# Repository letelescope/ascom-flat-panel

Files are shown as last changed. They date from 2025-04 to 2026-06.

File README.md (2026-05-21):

# Le Telescope Flat Panel 







[![Build with PlatformIO](https://img.shields.io/badge/build%20with-PlatformIO-orange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)](https://platformio.org/)

 

Open source *ASCOM* and *INDI* driven automated flat panel for astrophotography. 

> ⚠ **DISCLAIMER**  
> This project is still very much work in progress. None of it is likely/expected to work at this stage !

---

## Introduction

This project is an open source initiative, under the MIT license, by *Le Telescope*. This is the v2 of a fully automated and drivable motorized flat panel/dust cap. The device is nicknamed FFFP. Don't ask why! If you still want to know, see the  [misc. section](#miscellaneous) of this readme.

This project should contain all you need to build your own *ASCOM* and/or *INDI* driven Flat Panel. 

- [firmware](./firmware/fffp_firmware/): Firware of the programble chip used to control the panel and its cover
- [drivers](./drivers/): Implementation of the drivers
  - [ASCOM](./drivers/ASCOM/) : Implementation of the *ASCOM* driver 
  - [INDI](./drivers/indi/) : Implementation of the *INDI* driver
- [electronics](./electronics/): Electronic schematics and PCB layouts
- [models](./models/): 3D models for the plat cap
- [specifications](./specifications/): Specifications of the project. Mainly the specs of the communication protocol between the drivers and the firmware.

This project, the protocol, the implementation of both the *ASCOM* driver and the firmware, the electronics and the 3D models are heavily inspired by the the work  of [Dark Sky Geek](https://github.com/jlecomte/). And more precisely: 
- [ascom-flat-panel](https://github.com/jlecomte/ascom-flat-panel)
- [ascom-wireless-flat-panel](https://github.com/jlecomte/ascom-wireless-flat-panel)
- [ascom-telescope-cover-v2](https://github.com/jlecomte/ascom-telescope-cover-v2)

Kudos to him. 

The Pulse Width Modulation (PWM), used to control the panel brightness, implementation is heavily inspired, or more accurately shamelessly ripped, from the work of [Khoih Hoang](https://github.com/khoih-prog) and more precisely [SAMD_PWM](https://github.com/khoih-prog/SAMD_PWM/). 

Kudos to him too.

Finally te INDI driver architecture follows very closely the official [Gemini Flat Panel](https://github.com/indilib/indi/blob/master/drivers/auxiliary/gemini_flatpanel.h) as well as teh [Flip Flat](https://github.com/indilib/indi/blob/master/drivers/auxiliary/flip_flat.h) implemtentations. 

----

## Construction

### Why a "motorized flat panel" ? And what do we mean by "motorized flat panel" ?

In this scenario a flat panel is made of two things
- A light panel with variable brightness
- A motorized cover

The cover is motorized using a servo motor and held in open/close positions using simple magnets. The lightpanel is made 
- either using LEDs and the variable brightness is achieved via pulse width modulation (PWM). 
- or eusing a EL panel and the variable brightness is achived usi a DAC (Digital to Analog Converter) coupled to an OA (Operation Amplifier) in non-inverting amplifier mode. 

This "electronico-mechanical" assembly is controlled via a SAMD21 based board with a custom firmware within a custom PCB. The SAMD21 is particullarly suited because:

- it can output 5V, that is needed to power the servo.
- it can output +3V3 and allow us to choose between 3V and 5V to power the LEDs.
- it has 16 bits timer counters necessary to achieve fast PWM. We do not want flickering flats...
- it has a real DAC output pin to alow "easy" dimming of a flat panel.

One can connect and send commands to the flat-panel using Serial (COM Port) over USB. When plugged in the device will be recognized by windows/linux as a COM device. 

Finally this is driven by ASCOM/INDI, such that one can fully automate taking flats following the acquisition sessions of our beloved night sky targets. 

> ⚠ **DISCLAIMER**  
> This project is built around the Seeeduino XIAO board that uses the ATSAMD21G18A-MU chip. This is the only board that we tested. This may work on other boards that uses these SAMD21 chips, but this may need some rework on the firware, the PCB layout and the mechanical assembly. 

Now that we have the big picture let's get real and build the thing !

[INSERT HERE SOME PHOTOS]

### Pre-requisites

Very few pre-requisites are necessary in order to build the flat panel. More precisely one will need to:

- have access to a 3D printer, to print the mechanical assembly parts
- have some soldering skills and a soldering kit, to solder the components to the custom PCB
- install PlateformIO, to upload the firmware
- love "diy-ing", because you may need to want/need to tweaks things a bit to make it work in your setup. 
  
And that's it ! For instance you won't need software developpement skills as both the driver and the firmware are usable as is. Moreover, the ASCOM driver installer is already pre-compiled and made available to the download. Unfortunaltely one cannot make an "installer" for the arduino firware. Yet using PlaterfomIO to upload the firmware is a matter of three clicks. 

> We chose PlatformIO instead of ArduinoIDE due to recent concerns about Arduino's Open Source commitment under Qualcomm, and ,icing on the cake, PlatformIO provides superior dependency and library management.

### Bill of material 

[TODO] ADD BILL OF MATERIAL 

### Get a coherent version. 

We heavily use the git version control "tags" to label released versions. We also leverage the "GitHub releases" that add the possibility to pin "binaries" (ie anything we want PCB layouts, Driver installers, mechanincal assembly 3D printer files,...) on "tagged" versions. 

When we deem a version is "usable" we tag it, ie we freeze this repository at a particular "commit", and create a release out of it. 

To access the various releases just got the [releases page](https://github.com/letelescope/ascom-flat-panel/releases/) of this repository.

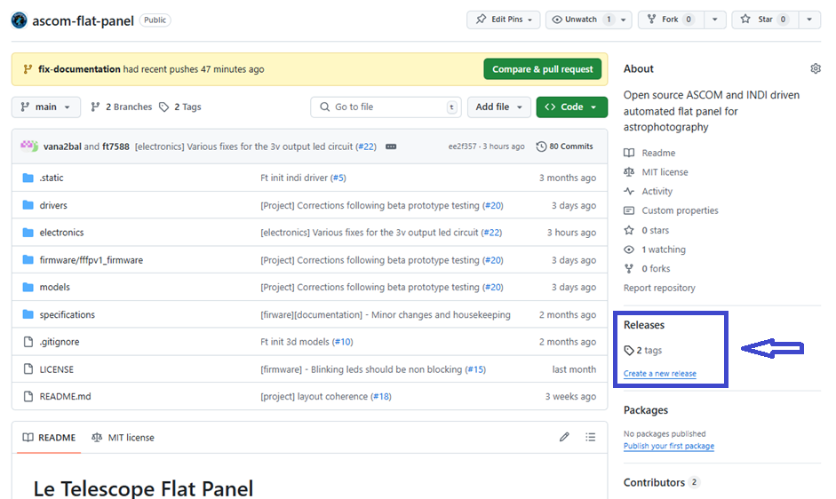
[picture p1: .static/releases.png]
Access the releases


And choose the release you want. The latest should be the "better". 

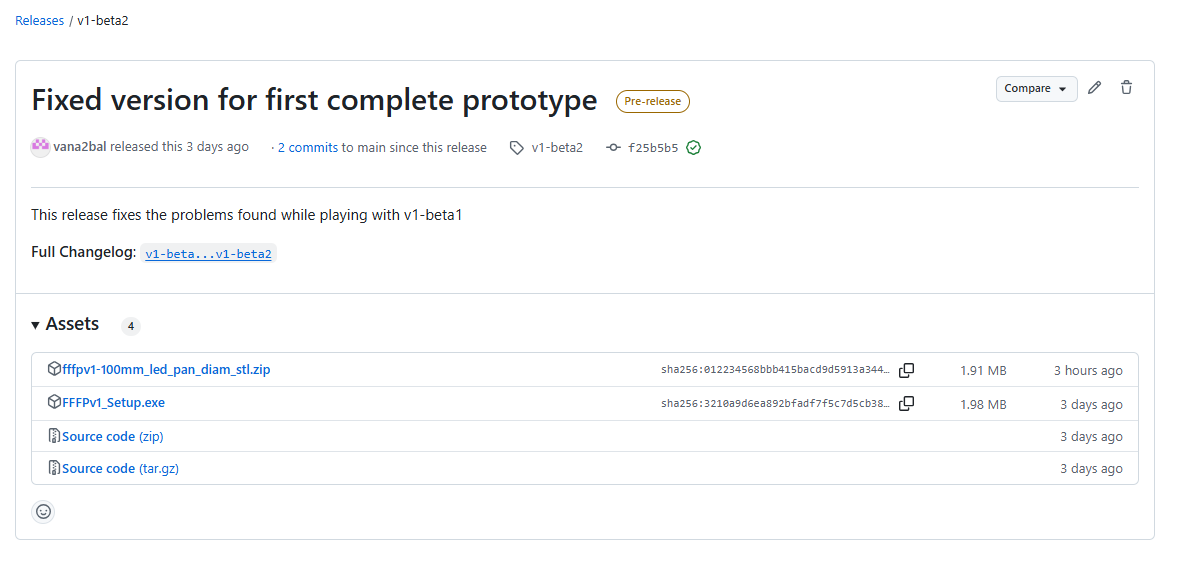
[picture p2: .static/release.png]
Access the content of a release


We recommend that you use one of these released version as they are coherent and tested. Be careful some release are labelled "pre-release" and should be used with caution. Those are developpement, beta and alpha version. Use it at you own risk like all the material on this repository. But even more in this case :D. 

In the same spirit, we do not recommend you use the "head" of the main branch (or any other branch) of this repository as this is work in progress and hence is not guaranteed to be stable or even usable...

> If you already have an FFFPV1, please note that both drivers and firmware **should** be backward compatible. You can use the latest version of both the ASCOM driver with your FFFPV1 without any issue and vice-versa: upload the new firmware on your FFFPV1 device and still use the legacy v1 driver. Yet we recommend you use the latest version of the driver, the firmware, the electronic circuit and the assembly as they all have been improved coherently.

### Electronic circuit

We provide three options for the electronic circuit. The difference is made on wether you want to use a led panel or a EL panel (You may not have the choice, as LED panels are restricted to smaller diameters). 

#### EL Panel option

This is certainely the "go to" solution, as this allows for a slicker and ligther mechanical assembly. Ans the electronics are not that much more difficut. 

- The The Pin "AO" (DAC) of the Seeeduino XIAO is used to control the LED brightness:
  - Is is directly connected to the non-invervint pin of ta TLC272 Op.Amp. The Ration of R1/R2 controls the amplifying contant (R = 1 + R1/R2) 
  - The output of the TLC272 is connected to the base of a  darlington transistor. Such that more current can flow to the EL Driver without worring too much about the life expectency of the TLC272
  -  The +12v needed for the Op Amp and the Driver is obtained using a DC/DC regulator

> ⚠ **WARNING**  
> The choice of Pin AO for DAC is not random. This is the only one on the Seeeduino XIAO (and SAM-D21 chips) capable to produce proper DAC. Please [see](https://ww1.microchip.com/downloads/en/DeviceDoc/SAM_D21_DA1_Family_DataSheet_DS40001882F.pdf). 

- The Pins "5,6,7"  of the Seeeduino XIAO are used for power control, position control and servo feedback:
  - Power control is connected, via a voltage divider bridge, to the gate of a IRLZ34N MOSFET.
  - Feedback is directly connected to the feedback pin of the servo.
  - Position control is directly connected to the position control pin of the servo.
  
- Servo VCC and Servo ground are decoupled using diodes.

- +12V and +5V are decoupled from ground using 10μF capacitors. It acts both as
  - an energy storage for a stable +5V/+12V output.
  - a "wire" for very high frequency spurious oscillations and effectively ground them. 

#### LED Panel schematics

This should be the go solution for most setups. Yet if you setup si particularly slow you may want to check the led versions. 

Here is the schematics for this option

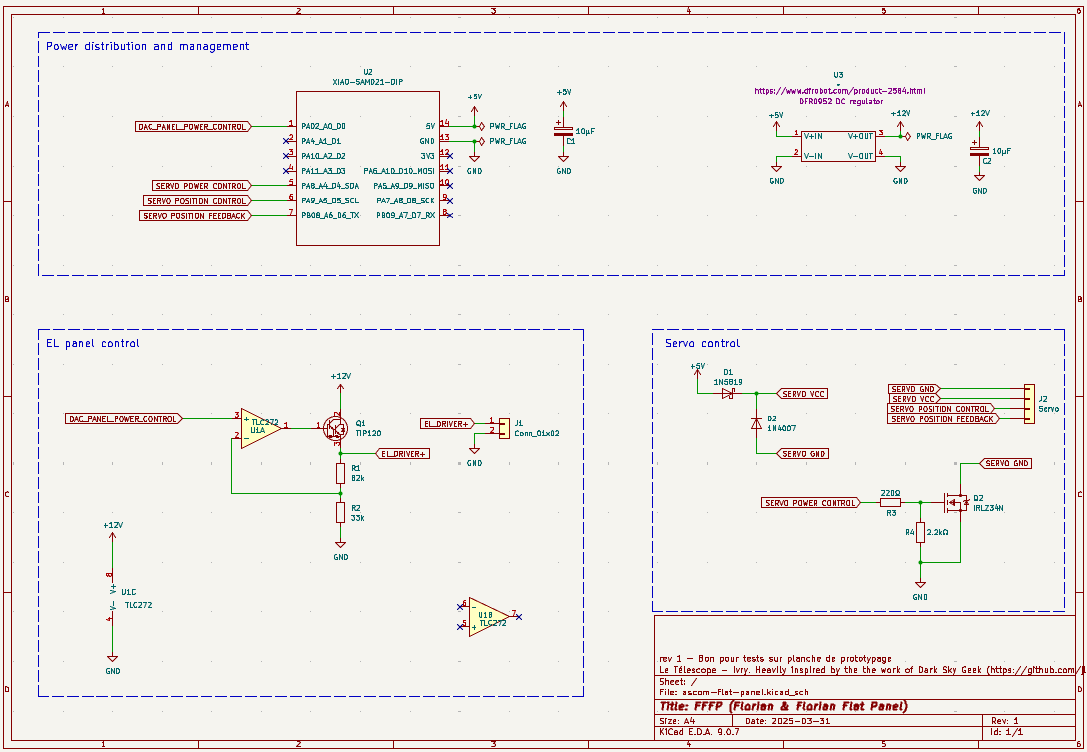
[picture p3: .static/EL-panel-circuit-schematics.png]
Circuit with EL panel


#### LED panel option

There are two options regarding the tension value used to power the LEDs: either +3V3 or +5V. But appart from that the two circuits share the same principles:

- The Pin "8"  of the Seeeduino XIAO is used to control the LED brightness:
  + It is connected, via a voltage divider bridge, to the gate of a IRLZ34N MOSFET.
  - The "+"terminal of the LEDs (strip or panel) is plugged to the constant +3V3 (or +5V) output of the Seeeduino
  - The "-" terminal of the LEDs (strip or panel) is connected to the drain of the IRLZ34N MOSFET. 
  - The source of the MOSFET is grounded. 
  - High frenquency PWM is used to swich rapidly ON and OFF the MOSFET, and allow to control the effective tension applied to the LEDs. 

> ⚠ **WARNING**  
> The choice of Pin 8 for PWM is not random. Not all pins of Seeeduino XIAO (and SAM-D21 chips) are capable to produce high frequency PWM. That's possible with Pin 8 because it use timer counter TCC1 which is 16bits.  And If you want to choose another pin please check the [documentation](https://ww1.microchip.com/downloads/en/DeviceDoc/SAM_D21_DA1_Family_DataSheet_DS40001882F.pdf) first. 

- The Pins "5,6,7"  of the Seeeduino XIAO are used for power control, position control and servo feedback:
  - Power control is connected, via a voltage divider bridge, to the gate of a IRLZ34N MOSFET.
  - Feedback is directly connected to the feedback pin of the servo.
  - Position control is directly connected to the position control pin of the servo.
  
- Servo VCC and Servo ground are decoupled using diodes.

- +5V (and +3V3 if needed) are decoupled from ground using 10μF capacitors. It acts both as
  - an energy storage for a stable +5V/+3V3 output.
  - a "wire" for very high frequency spurious oscillations and effectively ground them. 

##### The +3V3 output for LEDs

This is best suited for small refractors using fewer LEDs and/or fast optics. 

Here is the schematics for this option

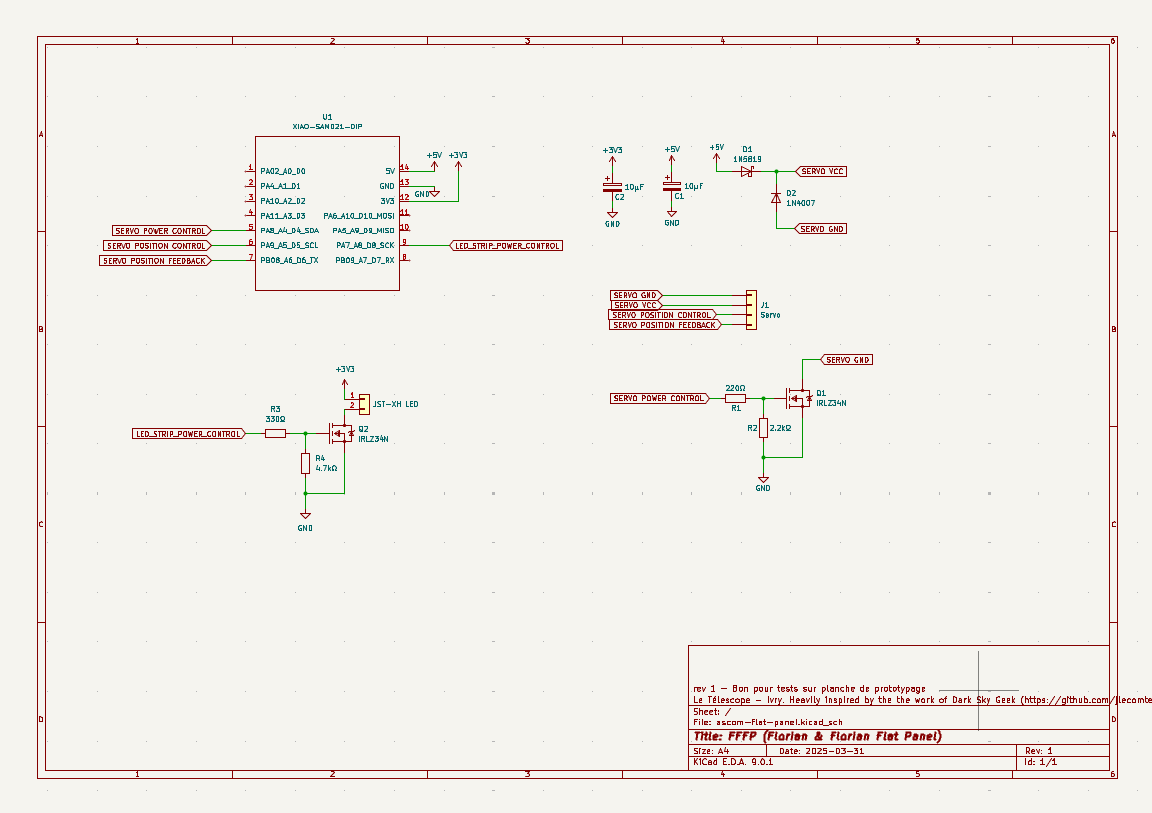
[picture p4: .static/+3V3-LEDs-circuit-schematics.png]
Circuit with +3V3 output for LEDs


##### The +5V output for LEDs

This is best suited for bigger tubes using a larger number of LEDs drawing more current. 

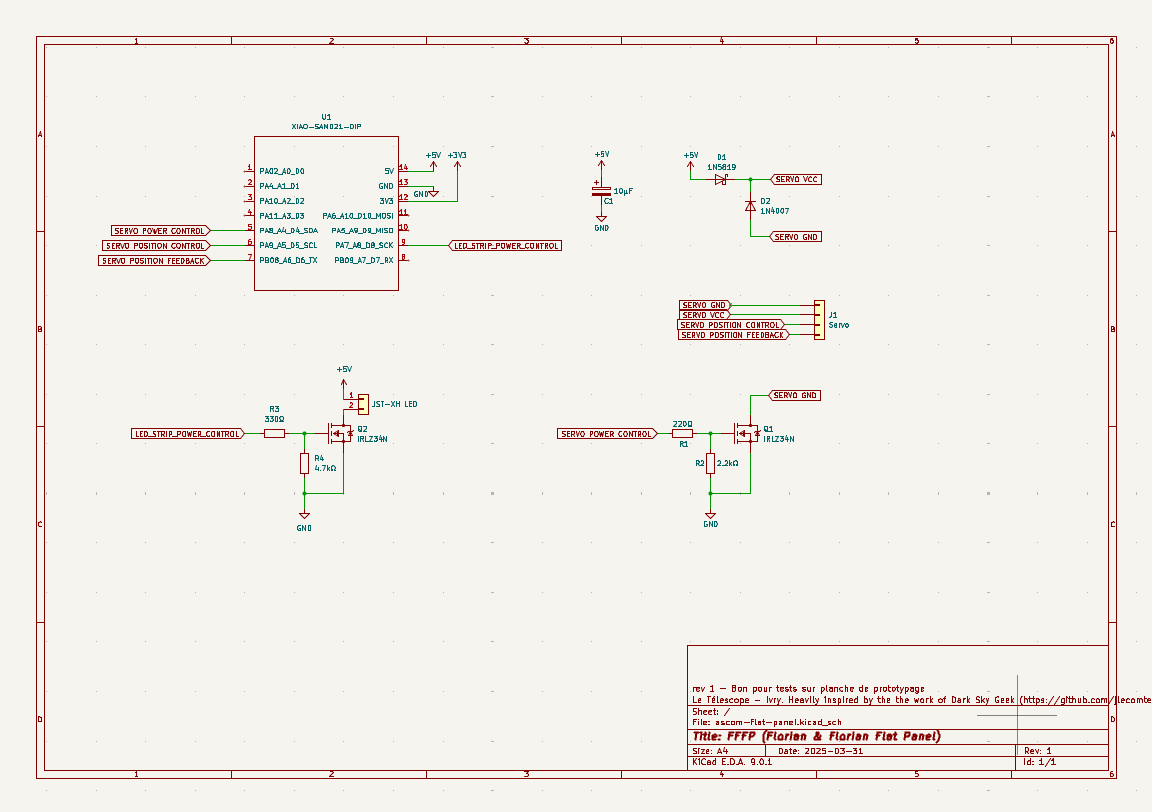
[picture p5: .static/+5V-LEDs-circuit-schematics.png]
Circuit with +5V output for LEDs


#### Cicruit layout breadbord validation

We recommend you prototype the circuit using breadbords first. 

- This can help you choose between the +5V and +3V3 version. A quick "hint", don't go for to bright ouputs for LEDs as a very bright panel is in fact not really needed when taking flats. Especially with fast optics. 
- This allows to check each component/part of the circuit independently. It's always better to find a faulty component before it is soldered on a PCB.
- It's always fun to prototype. 

Here is and example of what the "+5V" circuit may look like on a breadbord.

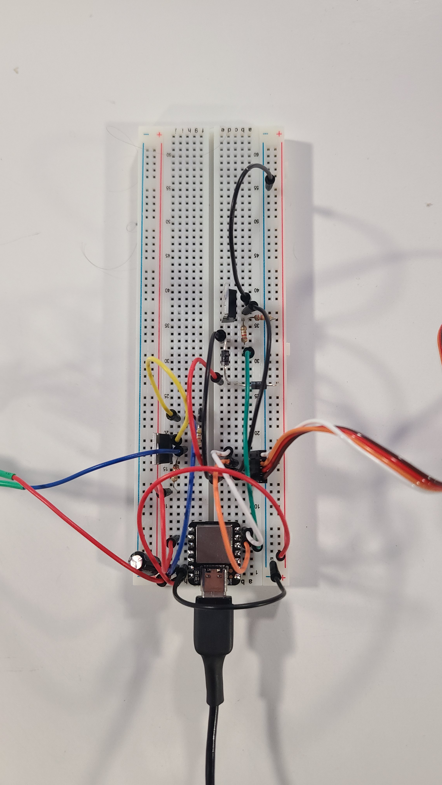
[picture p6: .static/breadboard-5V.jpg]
+5V circuit breadboard prototype
.

#### Printed Circuit Board

We had our PCBs printed by [PCBWay](https://www.pcbway.com/). If you do not modify the PCB layout and want to have it printed by PCBWay, you can just download one of the provided zip files that are pinned to the release (fffpv1-electronics-5V-LEDs-pcbway-files.zip or fffpv1-electronics-3V-LEDs-pcbway-files.zip, depending if you intend to use the +5V or +3V3 version).

If you want to modify the PCB layout, you have two options depending on the company you chose to print your PCB :
- If you chose PCBWay, just run a "Desing Rules Check" after your modifications are done to make sure there is no error (there may be warnings, but who cares about warnings ?). The PCBWay design rules are associated to the KiCAD project (they are implemented in the ascom-flat-panel.kicad_dru file). From here you can generate the fabrication files using the KiCAD interface and following the recommandations explained on the PCBWay website, OR you can simply install the PCBWay plugin for KiCAD, which will do the job for you in one click, and will drive you to the PCBWay website to complete your order (yes, we live in a fantastic era).
- If you chose another company, make sure their design rules are implemented to the KiCAD project. Depending on the company, you may find them in tables on the company's website and implement them using the KiCAD interface, or they can provide a .kicad_dru file you can use instead of the one we provide. Then perform a "Desing Rules Check" to check your modifications. Then you can generate the fabrication files using the KiCAD interface and following the recommandations provided by your supplier, or you can find out if there is a KiCAD plugin to do the job. Some suppliers will just take your KiCAD project and do all of this by their own, leaving you with basically nothing to do but creating an account and uploading your project (and pay, of course).

#### Firmware upload

#### Pre-requisite

The firmware needs to be uploaded using Visual Studio Code/PlateformIO . [PlateformIO setup section](#pre-requisites-1) of this documentation to set it. 

#### Upload the firware

1. Open the [firmware project](./firmware/fffp) from Visula Strudio Code/Plateform-IO. 

2. Connect the board via US. 
   
3. Select the board.
   
4. Click the "arrow" at the bottom to compile and upload the firmware on the board. 

The output should look something like: 

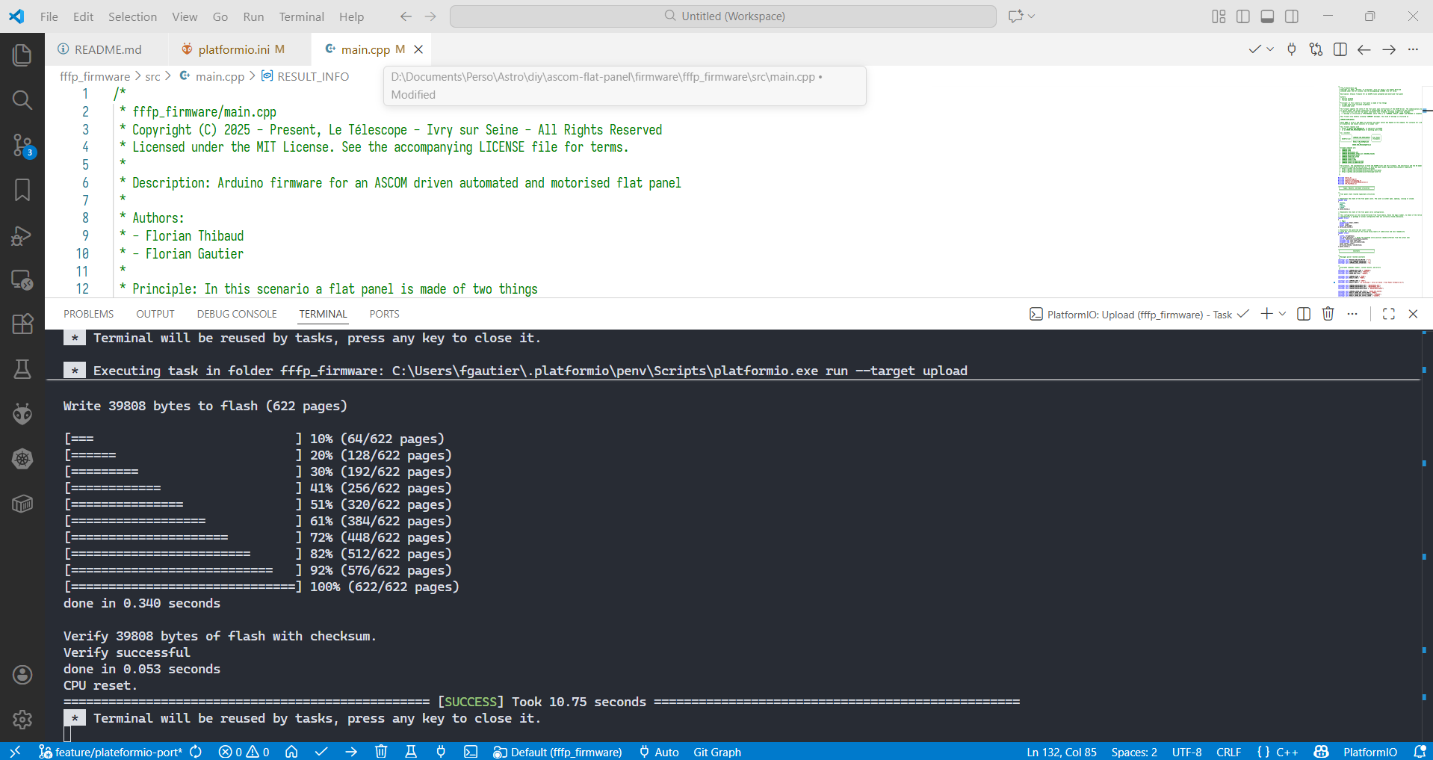
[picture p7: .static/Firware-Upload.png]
Arduino IDE firmware upload


#### Firmware checks

Once the firware is uploaded, do not disconnect the board yet. Still from the Arduino IDE open the "Serial Monitor". Once connected, in the console type:

``` console
COMMAND:PING
```
the board should answer

``` console
RESULT:PONG
```

Congrats! The Seeeduino is ready to act as your flat panel controller !

### Mechanical Assembly

Moving on to the actual print and build of the assembly. 

#### Prints from pre-designed assemblies

This repository (and therefore the tagged release version) contains a fully fonctional model. This is made to fit an Askar SQA-55 and uses premade 100mm led panel. It also feature an adapter to fit an Askar 71F. 

"Ready to print" STL files are also pinned to the release. Just download the fffpv1-100mm_led_pan_diam_stl.zip archive, unzip it. The archiver files are organized within two folders "Black" and "White". Files in he "black" repository can be printed in the color of your choice, but the one in the "white" folder should be printed using white PLA for better performance. This is especially true for the "spacer/diffuser" that, as its name suggests, helps homogenise the illumination of the panel.

#### Modification of pre-designed assemblies

#### Manufacturing sequence

#### Calibration of servo motor 

> ⚠ **WARNING**
> The firmware needs to be calibrated.

At first boot the LEDs will flash to indicate that it needs to be calibrated. 

> ⚠ **WARNING**
> Disconnect the servo from the mecanical assembly before launching the calibration procedure. 

Then from the IDE connect to the board and using the Arduino serial monitor send (type) the "command" 

``` console
COMMAND:COVER_CALIBRATION_RUN
``` 

The device should perform its calibration procedure and reply with 

``` console
RESULT:COVER_CALIBRATION_RUN@OK
```

Once it has completed, re-attach the right arm to the servo. The device is now ready to be used.

### ASCOM Driver Install

You can either used the installer to install the ASCOM driver or build it from source. For the sake of simplicity we recommend using the installer. 

#### Pre-compiled installer

The installer is pined on each release [releases page](https://github.com/letelescope/ascom-flat-panel/releases/). 

1. From the wanted release, download the file "FFFP_Setup.exe". 

2. "Double-click" on the downloaded file to launch it. 

   > ⚠ **WARNING**
   > Windows will warn that the publisher is unknown. This is perfectly fine. As buying a verified signing key, is definitely not a priority for us, we could not sign the installer. Yet this is perfectly safe to use it. 

3. Follow the instruction to install and register the driver. 

Congrats! You just installed the driver !

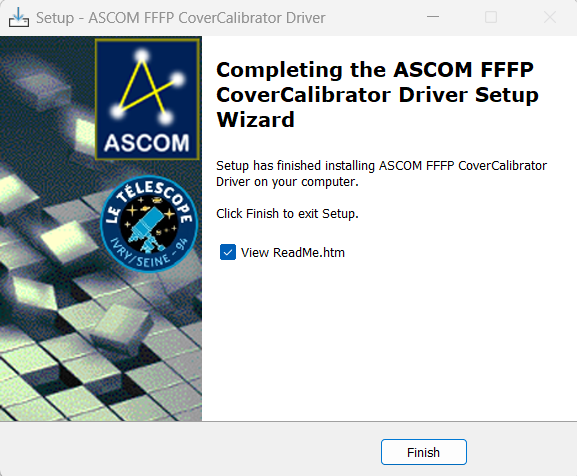
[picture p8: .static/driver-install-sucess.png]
driver install


#### Build from sources

To build it from source please check the relevant section of the "developpement documentation". 

#### Driver validation

Once install is complete, one can use the ASCOM profile explorer tool to check that this was installed properly. From the ASCOM profile explorer check that the *ASCOM CoverCalibrator Drvier for Le Telescope FFFP* is listed in the Cover Calibrators. 

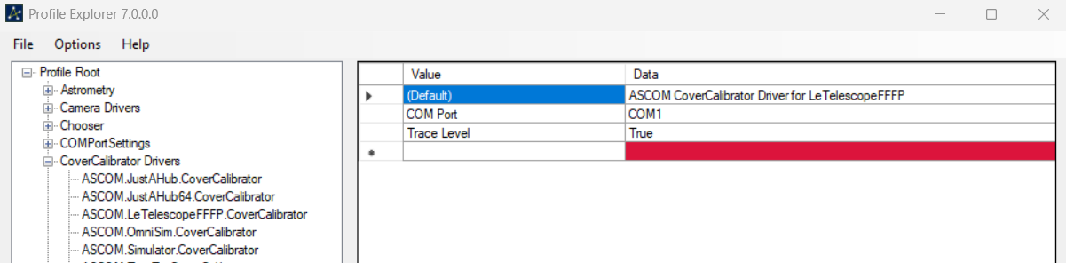
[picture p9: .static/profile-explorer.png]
ASCOM CoverCalibrator Drvier for Le Telescope FFFP
 

### INDI Driver

> ⚠ **WARNING**
> INDO driver is NOT functional DO NOT USE IT. 

---

## Testing

To avoid mass troubleshooting, one can test each component fairly separately. Below are listed some tests that can be used to validate the setup. Going from "unit test" to big-bang integration tests from your favourite acquisition software. 

### Firware "unit" testing

Once the firware is uploaded, one should already have tested that the seeduino was responsive. If not, reconnect the board via USB. From the Arduino IDE, open the "Serial Monitor". Once connected, in the console type:

``` console
COMMAND:PING
```
the board should answer

``` console
RESULT:PONG
```
If that's not the case, please make sure that you uploaded the (correct version of the) firmware firt. 

If that is indeed the case, congrats you are ready to test more "interesting" features of the firmware.

#### Set brightness levels

From the "Serial Monitor", in the console type the following command to adjust the LED panel brightness level:

``` console
COMMAND:BRIGHTNESS_SET@1024
```
the board should answer in the console

``` console
RESULT:BRIGHTNESS_SET@1024
```
In parallel, if it is connected to the board, the light panel should have been turned on. Feel free to change the value (number after the '@') to adjust the brightness. Max allowed value is 2047 and min value is 0. 

Use ```COMMAND:BRIGHTNESS_RESET``` to switch off the panel.

Congrats the variable light panel is functionnal. 

#### Open/Close the cover

> ⚠ **WARNING**
> To be able to open/close the panel, the panel should be calibrated first. Check the "mechanical assembly" section for the procedure. 

When turned on, the panel should be closed. To open it, from the "Serial Monitor", in the console type the following command:

``` console
COMMAND:COVER_OPEN
```
the panel should start moving and the board should answer in the console

``` console
RESULT:COVER_OPEN@OK
```

Once open to close it simply type in the consle

``` console
COMMAND:COVER_CLOSE
```
the panel should start moving and the board should answer in the console

``` console
RESULT:COVER_CLOSE@OK
```

Finally at any given time, to know the status of the mecanical panel type 

``` console
COMMAND:COVER_GET_STATE
```
the panel should start moving and the board should answer in the console

``` console
RESULT:COVER_GET@{panel.cover}
```

where panel.cover is string human readable translation of the current cover state. Possible values are in [**OPEN**, **OPENING**, **CLOSING**,]; 

Congrats the motorized cover is functionnal. 

### Driver "unit testing"

After install completion, one should already have used the ASCOM profile explorer tool to check that this was installed properly. If that's not the case from the ASCOM profile explorer check that the *ASCOM CoverCalibrator Drvier for Le Telescope FFFP* is listed in the Cover Calibrators. 

ASCOM CoverCalibrator Drvier for Le Telescope FFFP 

1. Then check that the driver is instiable using the ASCOM diagnostic tools
   
   a. Select the "Cover Calibrator" device type and elect the "FFPV1 Cover Calibrator"

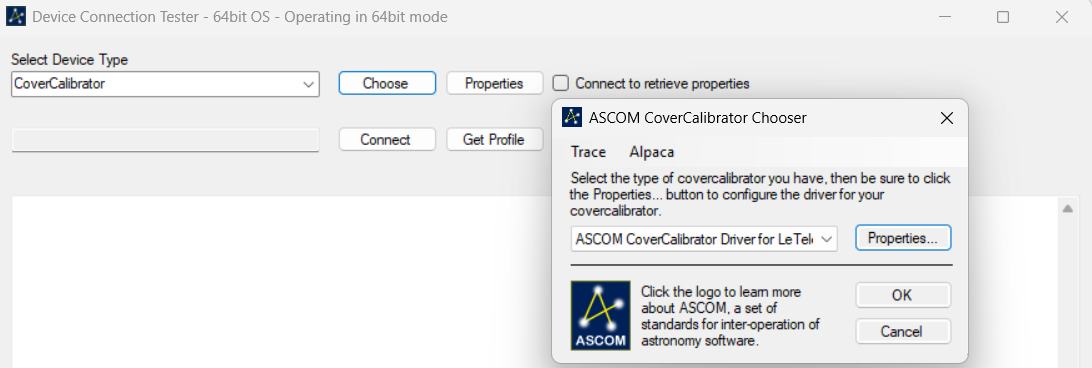
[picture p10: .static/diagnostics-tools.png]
Cover Calibrator device type


   b. Find and configure the "properties" of the driver

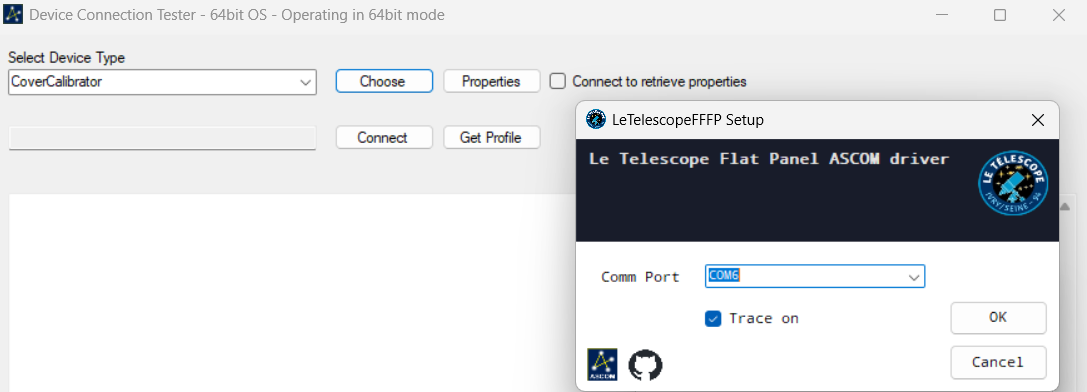
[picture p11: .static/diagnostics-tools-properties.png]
Driver properties


   b. Connect to the driver. Expect nothing much to happen. 

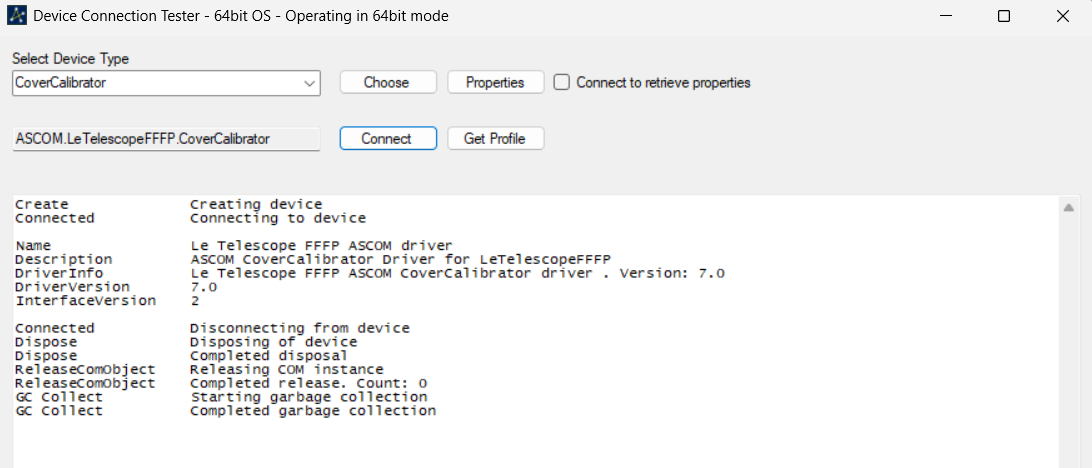
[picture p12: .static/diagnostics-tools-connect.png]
Connect driver


Congrats the driver seems to work as expected !

### Connect to the panel from N.I.N.A via ASCOM

Great ! If you read this, at this stage, the firware, the driver and the mecanical assembly should work, or at least one should be confident enough that they are working. Let's make the final test (and the only one relevant in fact). Let's take some flats from N.I.N.A. 

## Usage

The FFFP should be now be fully usable and drivable from N.I.N.A. 

### Flat-Panel Connection

Let's connect to the flat panel. 

0. Plug the flat panel to the computer via USB

In the equipment tab, from the flat panel section:

1. Select the *ASCOM CoverCalibrator Drvier for Le Telescope FFFP*.
2. Click the gear icon and select the correct COM Port. 
3. Hit OK to save the configuration.
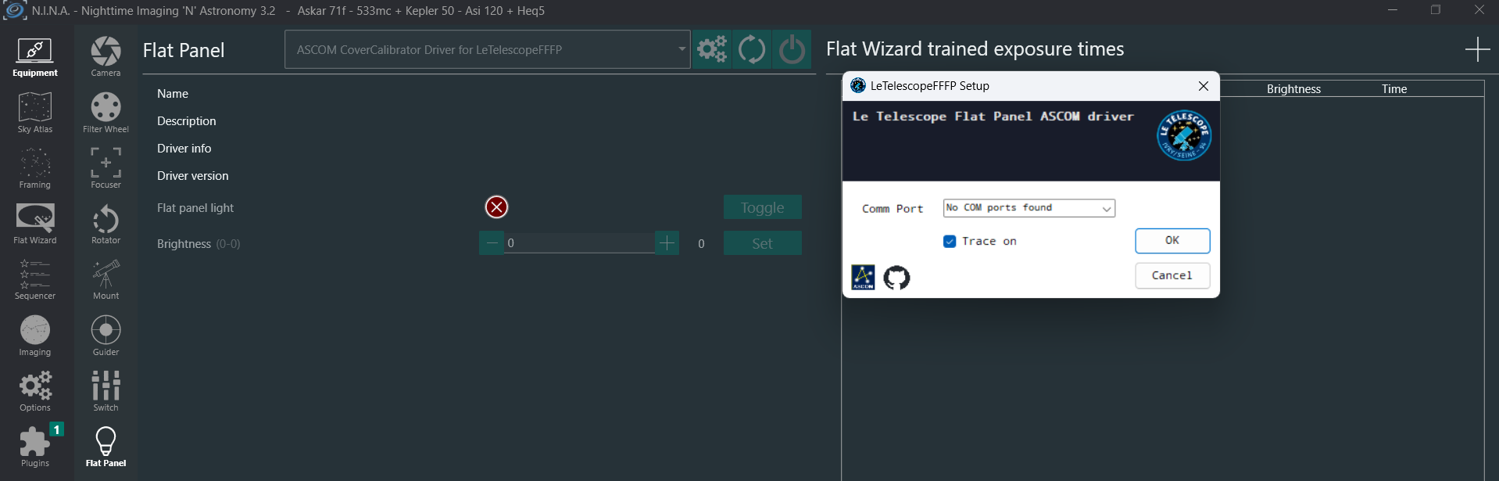
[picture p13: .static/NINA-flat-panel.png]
N.I.N.A Flat Panel equipement section
   

4. Click the "power" button to connect to the flat panel. 
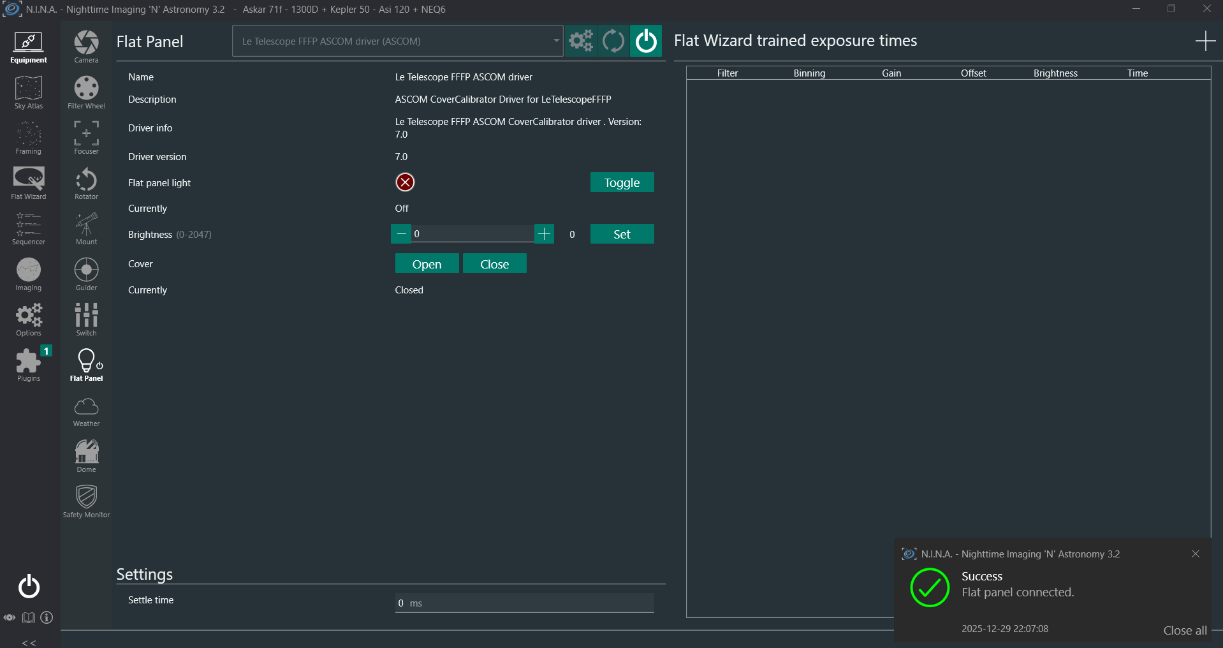
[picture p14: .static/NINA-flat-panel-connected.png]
N.I.N.A Flat Panel connection
   

From there you can turn on and off the panel, set the wanted brightness and/or open/close the cover. 

### N.I.N.A smart flats

Let's now use the N.I.N.A smart flats capabilities to automate flat frames recording.

#### Auto-exposure

#### Auto-brightness

---

## Developpement 

### Principle

In this scenario a flat panel is made of two things
- A light panel with variable brightness
- A motorized cover

The firmware updates the state of the flat panel upon instructions of the (*ASCOM* or *INDI*) driver. The communication protocol is serial based. The serial connection is established via USB. Here is a a summary of the protocol 
- Both the driver and the flat panel (its firmware) exchange single line messages; ie terminated by '\n'.
- A message is structured as TYPE:MESSAGE, where TYPE is in "COMMAND, RESULT, ERROR" and MESSAGE is alaphanumerical with spaces and "@"

The driver emmits and the firmware handles the incoming "COMMAND" messages. This kind of message is stuctured as 

- `COMMAND:NAME[@ARGS]` where NAME is [A-Z_]+ and ARGS may be optional or mandatory and their nature may depend on the command.

The firmware then responds with 
- either a `RESULT:CMD_NAME@VALUE` if operation succeeded
- or an `ERROR:ERR_MESSAGE@DETAILS` if anything went wrong

In a nutshell

     -----------------                           ------------
    |                 |                         |            |
    |      Driver     | COMMAND:CMD_NAME[@ARGS] | Flat Panel |
    | (ASCOM or INDI) | --------------------->  | (firmware) |
    |                 | <---------------------  |            |
     -----------------  RESULT:CMD_NAME@VALUE    ------------
                                or
                        ERROR:ERR_MESSAGE@DETAILS

More details on this protocol are provided in [protocol.md](./specifications/protocol.md)

### Softwares developpement and compilations

#### Seeduino firmware

The firware is entirely buildable and uploadable using the Arduino IDE
 
##### Pre-requisites 

- [Download](https://code.visualstudio.com/download) and install the Visual Studio Code or the IDE of your choice
- [Download](https://platformio.org/install/ide) PlatformIO IDE and/or install the PlatformIO extension for Visual Studio Code
- No need to download and configure the Seeduino XIAO board for PlateformIO as this is already done in the [platformio.ini](./firmware/fffp_firmware/platformio.ini) file of the firmware project.
- No need to download and install the official Adafruit SleepyDog library  as this is already done in the [platformio.ini](./firmware/fffp_firmware/platformio.ini). This is used to properly handle disconnection. 

##### Compile and upload the firmware

1) Using PlateformIO IDE, open the [project](./firmware/fffp_firmware/)

2) Click "PlateformIO: Build" to compile the firmware. The output should be something like 
   ``` console
   Processing seeed_xiao (platform: atmelsam; board: seeed_xiao; framework: arduino)
   --------------------------------------------------------------------------------------------------------------------------------------------------
   Verbose mode can be enabled via `-v, --verbose` option
   CONFIGURATION: https://docs.platformio.org/page/boards/atmelsam/seeed_xiao.html
   PLATFORM: Atmel SAM (8.3.0) > Seeeduino XIAO
   HARDWARE: SAMD21G18A 48MHz, 32KB RAM, 256KB Flash
   DEBUG: Current (atmel-ice) External (atmel-ice, blackmagic, jlink)
   PACKAGES:
    - framework-arduino-samd-seeed @ 1.8.5
    - framework-cmsis @ 2.50400.181126 (5.4.0)
    - framework-cmsis-atmel @ 1.2.2
    - toolchain-gccarmnoneeabi @ 1.70201.0 (7.2.1)
   LDF: Library Dependency Finder -> https://bit.ly/configure-pio-ldf
   LDF Modes: Finder ~ chain, Compatibility ~ soft
   Found 20 compatible libraries
   Scanning dependencies...
   Dependency Graph
   |-- Servo @ 1.3.0
   |-- Adafruit SleepyDog Library @ 1.6.5
   |-- FF_Flat_Panel
   |-- FlashStorage @ 0.5.0
   |-- SAMD21_PWM
   Building in release mode
   Compiling .pio\build\seeed_xiao\src\main.cpp.o
   Compiling .pio\build\seeed_xiao\libae5\Servo\avr\Servo.cpp.o
   Compiling .pio\build\seeed_xiao\libae5\Servo\esp32\Servo.cpp.o
   Compiling .pio\build\seeed_xiao\libae5\Servo\mbed\Servo.cpp.o
   Compiling .pio\build\seeed_xiao\libae5\Servo\megaavr\Servo.cpp.o
   Compiling .pio\build\seeed_xiao\libae5\Servo\nrf52\Servo.cpp.o
   Compiling .pio\build\seeed_xiao\libae5\Servo\renesas\Servo.cpp.o
   Compiling .pio\build\seeed_xiao\libae5\Servo\sam\Servo.cpp.o
   Compiling .pio\build\seeed_xiao\libae5\Servo\samd\Servo.cpp.o
   Compiling .pio\build\seeed_xiao\libae5\Servo\stm32f4\Servo.cpp.o
   Compiling .pio\build\seeed_xiao\libae5\Servo\xmc\Servo.cpp.o
   Compiling .pio\build\seeed_xiao\libae5\Servo\zephyr\Servo.cpp.o
   Compiling .pio\build\seeed_xiao\lib2bf\Adafruit SleepyDog Library\Adafruit_SleepyDog.cpp.o
   Compiling .pio\build\seeed_xiao\lib2bf\Adafruit SleepyDog Library\utility\WatchdogAVR.cpp.o
   Compiling .pio\build\seeed_xiao\lib2bf\Adafruit SleepyDog Library\utility\WatchdogESP32.cpp.o
   Compiling .pio\build\seeed_xiao\lib2bf\Adafruit SleepyDog Library\utility\WatchdogESP8266.cpp.o
   Compiling .pio\build\seeed_xiao\lib2bf\Adafruit SleepyDog Library\utility\WatchdogKinetisK.cpp.o
   Compiling .pio\build\seeed_xiao\lib2bf\Adafruit SleepyDog Library\utility\WatchdogKinetisL.cpp.o
   Compiling .pio\build\seeed_xiao\lib2bf\Adafruit SleepyDog Library\utility\WatchdogNRF.cpp.o
   Compiling .pio\build\seeed_xiao\lib2bf\Adafruit SleepyDog Library\utility\WatchdogRP2040.cpp.o
   Compiling .pio\build\seeed_xiao\lib2bf\Adafruit SleepyDog Library\utility\WatchdogSAMD.cpp.o
   Compiling .pio\build\seeed_xiao\libc78\FlashStorage\FlashStorage.cpp.o
   Archiving .pio\build\seeed_xiao\libae5\libServo.a
   Compiling .pio\build\seeed_xiao\FrameworkArduinoVariant\variant.cpp.o
   Compiling .pio\build\seeed_xiao\FrameworkArduino\IPAddress.cpp.o
   Compiling .pio\build\seeed_xiao\FrameworkArduino\IPv6Address.cpp.o
   Archiving .pio\build\seeed_xiao\lib2bf\libAdafruit SleepyDog Library.a
   Compiling .pio\build\seeed_xiao\FrameworkArduino\Print.cpp.o
   Compiling .pio\build\seeed_xiao\FrameworkArduino\Reset.cpp.o
   Compiling .pio\build\seeed_xiao\FrameworkArduino\Retarget.cpp.o
   Compiling .pio\build\seeed_xiao\FrameworkArduino\SERCOM.cpp.o
   Archiving .pio\build\seeed_xiao\libc78\libFlashStorage.a
   Archiving .pio\build\seeed_xiao\libFrameworkArduinoVariant.a
   Compiling .pio\build\seeed_xiao\FrameworkArduino\Stream.cpp.o
   Compiling .pio\build\seeed_xiao\FrameworkArduino\StreamString.cpp.o
   Compiling .pio\build\seeed_xiao\FrameworkArduino\Tone.cpp.o
   Compiling .pio\build\seeed_xiao\FrameworkArduino\USB\CDC.cpp.o
   Compiling .pio\build\seeed_xiao\FrameworkArduino\USB\PluggableUSB.cpp.o
   Compiling .pio\build\seeed_xiao\FrameworkArduino\USB\SAMD21_USBDevice.cpp.o
   Compiling .pio\build\seeed_xiao\FrameworkArduino\USB\USBCore.cpp.o
   Compiling .pio\build\seeed_xiao\FrameworkArduino\USB\samd21_host.c.o
   Compiling .pio\build\seeed_xiao\FrameworkArduino\Uart.cpp.o
   Compiling .pio\build\seeed_xiao\FrameworkArduino\WInterrupts.c.o
   Compiling .pio\build\seeed_xiao\FrameworkArduino\WMath.cpp.o
   Compiling .pio\build\seeed_xiao\FrameworkArduino\WString.cpp.o
   Compiling .pio\build\seeed_xiao\FrameworkArduino\abi.cpp.o
   Compiling .pio\build\seeed_xiao\FrameworkArduino\avr\dtostrf.c.o
   Compiling .pio\build\seeed_xiao\FrameworkArduino\base64.cpp.o
   Compiling .pio\build\seeed_xiao\FrameworkArduino\cbuf.cpp.o
   Compiling .pio\build\seeed_xiao\FrameworkArduino\cortex_handlers.c.o
   Compiling .pio\build\seeed_xiao\FrameworkArduino\delay.c.o
   Compiling .pio\build\seeed_xiao\FrameworkArduino\hooks.c.o
   Compiling .pio\build\seeed_xiao\FrameworkArduino\itoa.c.o
   Compiling .pio\build\seeed_xiao\FrameworkArduino\libb64\cdecode.c.o
   Compiling .pio\build\seeed_xiao\FrameworkArduino\libb64\cencode.c.o
   Compiling .pio\build\seeed_xiao\FrameworkArduino\main.cpp.o
   Compiling .pio\build\seeed_xiao\FrameworkArduino\math_helper.c.o
   Compiling .pio\build\seeed_xiao\FrameworkArduino\new.cpp.o
   Compiling .pio\build\seeed_xiao\FrameworkArduino\pulse.c.o
   Compiling .pio\build\seeed_xiao\FrameworkArduino\pulse_asm.S.o
   Compiling .pio\build\seeed_xiao\FrameworkArduino\startup.c.o
   Compiling .pio\build\seeed_xiao\FrameworkArduino\wiring.c.o
   Compiling .pio\build\seeed_xiao\FrameworkArduino\wiring_analog.c.o
   Compiling .pio\build\seeed_xiao\FrameworkArduino\wiring_digital.c.o
   Compiling .pio\build\seeed_xiao\FrameworkArduino\wiring_private.c.o
   Compiling .pio\build\seeed_xiao\FrameworkArduino\wiring_pwm.cpp.o
   Compiling .pio\build\seeed_xiao\FrameworkArduino\wiring_shift.c.o
   C:\Users\fgautier\.platformio\packages\framework-arduino-samd-seeed\cores\arduino\wiring_analog.c:35:12: warning: '_dacResolution' defined but not used [-Wunused-variable]
    static int _dacResolution = 10;
               ^~~~~~~~~~~~~~
   C:\Users\fgautier\.platformio\packages\framework-arduino-samd-seeed\cores\arduino\wiring_pwm.cpp: In function 'void noPwm(uint32_t)':
   C:\Users\fgautier\.platformio\packages\framework-arduino-samd-seeed\cores\arduino\wiring_pwm.cpp:374:13: warning: unused variable 'tcChannel' [-Wunused-variable]
        uint8_t tcChannel = GetTCChannelNumber(pinDesc.ulPWMChannel);
                ^~~~~~~~~
   Archiving .pio\build\seeed_xiao\libFrameworkArduino.a
   Linking .pio\build\seeed_xiao\firmware.elf
   c:/users/fgautier/.platformio/packages/toolchain-gccarmnoneeabi/bin/../lib/gcc/arm-none-eabi/7.2.1/../../../../arm-none-eabi/bin/ld.exe: warning: changing start of section .bss by 4 bytes
   c:/users/fgautier/.platformio/packages/toolchain-gccarmnoneeabi/bin/../lib/gcc/arm-none-eabi/7.2.1/../../../../arm-none-eabi/bin/ld.exe: warning: changing start of section .bss by 4 bytes
   c:/users/fgautier/.platformio/packages/toolchain-gccarmnoneeabi/bin/../lib/gcc/arm-none-eabi/7.2.1/../../../../arm-none-eabi/bin/ld.exe: warning: changing start of section .bss by 4 bytes
   c:/users/fgautier/.platformio/packages/toolchain-gccarmnoneeabi/bin/../lib/gcc/arm-none-eabi/7.2.1/../../../../arm-none-eabi/bin/ld.exe: warning: changing start of section .bss by 4 bytes
   c:/users/fgautier/.platformio/packages/toolchain-gccarmnoneeabi/bin/../lib/gcc/arm-none-eabi/7.2.1/../../../../arm-none-eabi/bin/ld.exe: warning: changing start of section .bss by 4 bytes
   Checking size .pio\build\seeed_xiao\firmware.elf
   Advanced Memory Usage is available via "PlatformIO Home > Project Inspect"
   RAM:   [=         ]   9.4% (used 3064 bytes from 32768 bytes)
   Flash: [==        ]  15.2% (used 39768 bytes from 262144 bytes)
   Building .pio\build\seeed_xiao\firmware.bin
   ========================================================== [SUCCESS] Took 7.97 seconds ==========================================================
   ```

   Don't worry to much about the warnings. Those are only warnings and can be safely igonered c.f. [arduino forum](https://forum.arduino.cc/t/web-ide-error-changing-start-of-section-by-4-bytes/1218049) and [adafruit forum](https://forums.adafruit.com/viewtopic.php?t=189483#p917530) .

1) Connect the Seeeduino and  "PlateformIO: Build"to test it

##### Warning - Firmware calibrarion

The firmware needs to be calibrated. At first boot the leds will flash to indicate that it needs to be calibrated. 

> **WARNING**
> Disconnect the servo from the mecanical assembly before launching the calibration procedure. 

Then from the IDE connect to the board and using the Arduino serial monitor send (type) the "command" 

``` console
COMMAND:COVER_CALIBRATION_RUN
``` 

The device should perform its calibration procedure and reply with 

``` console
RESULT:COVER_CALIBRATION_RUN@OK
```

Once it has completed, re-attach the right arm to the servo. The device is now ready to be used.

#### ASCOM Driver

The ASCOM driver is a C# .Net project that have been first created using the ASCOM 6 Visual Studio 2022 templates. Hence we recommend using Visual Studio 2022 when building it. Feel free to change this procedure to match your tooling. 

##### Pre-requisites 
 
- [ASCOM 7](https://github.com/ASCOMInitiative/ASCOMPlatform/releases/tag/v7.1.1) plateform
- [Visual Studio 2022](https://visualstudio.microsoft.com/fr/vs/). Comunity edition is totally fine. 
- A fully functional [ASCOM developper environement](https://ascom-standards.org/COMDeveloper/Index.htm) . Especiall, you may want to add the ASCOM "extensions" to Visual Studio.

##### Compile and register the driver

1) Open the ["solution"](./drivers/ASCOM/ASCOM_7_Driver/ASCOM_7_Driver.sln) from Visual Studio 2022

2) Compile the project using "Ctrl + Shift + B". The result in the console should look something like
  
   ``` console
   Génération démarrée à 14:12...
   1>------ Début de la génération : Projet : ASCOM_7_Driver, Configuration : Debug Any CPU ------
   1>  ASCOM_6_Driver -> D:\Documents\Perso\Astro\diy\ascom-flat-panel\ASCOM_drivers\ASCOM_7_Driver\bin\Debug\ASCOM.LeTelescopeFFFPV1.exe
   ========== Build : 1 réussite(s), 0 échec(s), 0 à jour, 0 ignorée(s) ==========
   ========== Build s’est terminée à 14:12 et a duré 10,405 secondes ==========
   ```

3) The first time you compile the server you must "register it" on the ASCOM plateform. Open an "elevated" command prompt (with admin priviledges) at the folder where the local server executable is located. Run the local server exe with the /regserver parameter which will create the entry that appears in the ASCOM Chooser. 
  
   ``` console
   .\ASCOM.LeTelescopeFFFP.exe /regserver
   ```

   **This registration only needs to be done once*.

4) You can now launch the driver from any ASCOM client, e.g. N.I.N.A or the ASCOM Diagnostic tool

##### Warning - When used with N.I.N.A

As of N.I.N.A 3.1.HF2, the "ASCOM device instance reference " is not disposed when connection failed. In our setup this may happen if the flat panel is not connected to the PC. In this scenario, the connection will fail, but a "driver process" will hang, waiting for N.I.N.A to dispose of the reference.

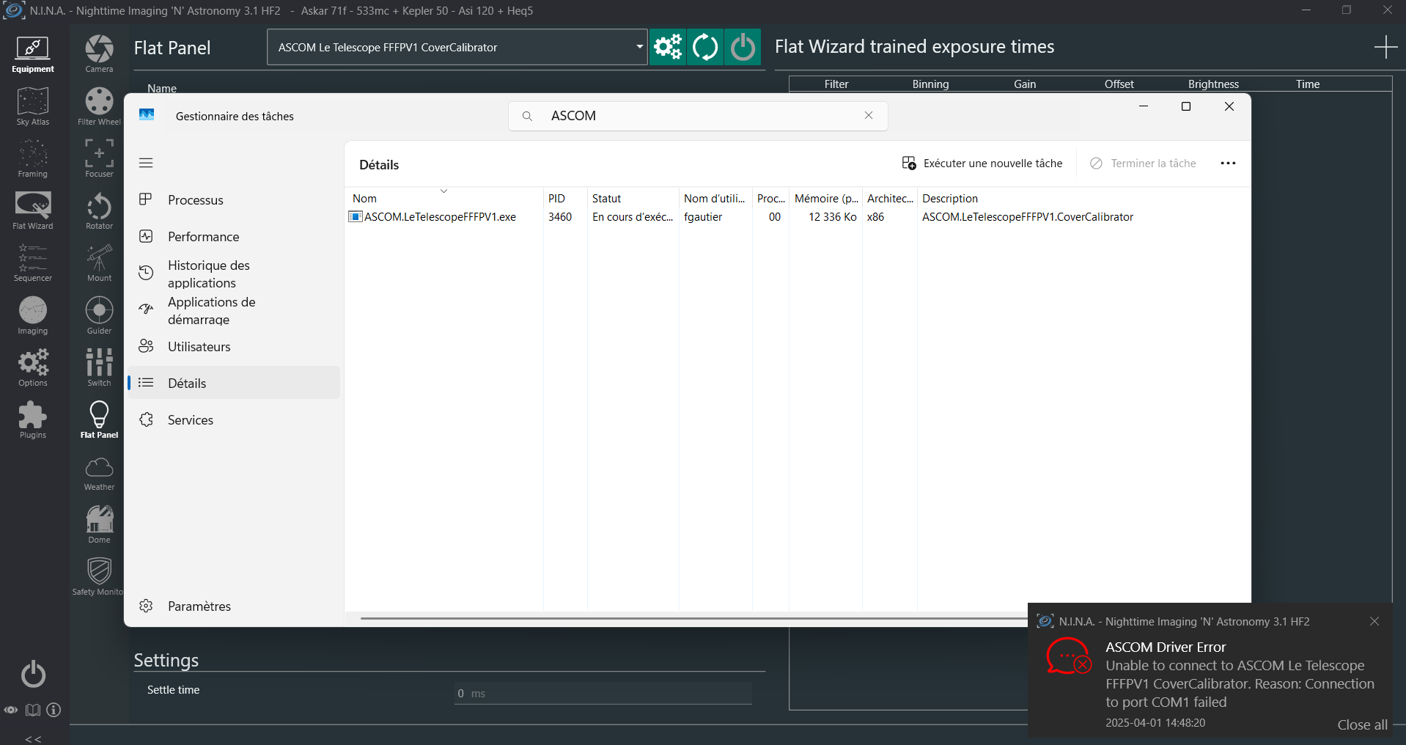
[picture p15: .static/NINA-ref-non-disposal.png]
NINA doeas not dispose of ASCOM reference


This is a known bug c.f. [nina-issue-1378](https://bitbucket.org/Isbeorn/nina/issues/1378/device-instance-not-disposed-when) and [ascom developers  group thread](https://ascomtalk.groups.io/g/Developer/topic/112002512). 

If this happens and some weird side effect happen on reconnection. Just disconnect from the device. Kill the dangling process in the task manager. And reconnect. 

### Indi driver

The indi driver is in its **really** early developement phase. It should no be used for anything else but developement. 

#### Pre-requisite

- A fully functional [Indi driver developer environement](https://docs.indilib.org/drivers/basics/project-setup.html). On Windows we recommend using a WSL2 environment. 
- One can also look at how to dev on "indi", c.f. the [getting started](https://docs.indilib.org/getting-started/)

#### Compile and install the driver

in the [indi](./drivers/indi/indi_driver/) directory, from VSCode integrated terminal or anyother terminal run

``` console
mkdir -p build
cd build
cmake -DCMAKE_INSTALL_PREFIX=/usr -DCMAKE_BUILD_TYPE=Debug ../
make
sudo make install
```

or 

``` console
./make-install.sh
```

The output should be something along the lines of:

``` console
-- The C compiler identification is GNU 13.3.0
-- The CXX compiler identification is GNU 13.3.0
-- Detecting C compiler ABI info
-- Detecting C compiler ABI info - done
-- Check for working C compiler: /usr/bin/cc - skipped
-- Detecting C compile features
-- Detecting C compile features - done
-- Detecting CXX compiler ABI info
-- Detecting CXX compiler ABI info - done
-- Check for working CXX compiler: /usr/bin/c++ - skipped
-- Detecting CXX compile features
-- Detecting CXX compile features - done
-- Found INDI: /usr/lib/x86_64-linux-gnu/libindidriver.so;/usr/lib/x86_64-linux-gnu/libindiAlignmentDriver.so (found version "2.1.9")
-- Found NOVA: /usr/lib/x86_64-linux-gnu/libnova.so
-- Found ZLIB: /usr/lib/x86_64-linux-gnu/libz.so (found version "1.3")
-- Found GSL: /usr/include (found version "2.7.1")
-- Performing Test COMPATIBLE_FORTIFY_SOURCE
-- Performing Test COMPATIBLE_FORTIFY_SOURCE - Success
-- Configuring done (2.3s)
-- Generating done (0.0s)
-- Build files have been written to: /home/florian/documents/diy/ascom-flat-panel/drivers/indi/indi_driver/build
[ 50%] Building CXX object CMakeFiles/indi_letelescope_fffp_flatpanel.dir/indi_letelescope_fffp_flatpanel.cpp.o
[100%] Linking CXX executable indi_letelescope_fffp_flatpanel
[100%] Built target indi_letelescope_fffp_flatpanel
[100%] Built target indi_letelescope_fffp_flatpanel
Install the project...
-- Install configuration: "Debug"
-- Installing: /usr/bin/indi_letelescope_fffp_flatpanel
-- Installing: /usr/share/indi/indi_letelescope_fffp_flatpanel.xml
```

## Miscellaneous

- *What is "Le Télescope" ?* This a french astronmy club located at Ivry sur Seine in the Paris suburbs. Please see the [website](https://letelescope.fr) for more informations.
- *Why is this panel nicknamed FFFPV1 ?* This stands for "Florian Florian Flat Panel v1" based on the name of the two orginal authors. 
- *Special thanks to Fabrice Houvet*. He was, with his 3D printer of real help when prototyping this flat panel.

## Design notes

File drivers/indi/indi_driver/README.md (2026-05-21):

# Build and install driver

## Pre-requisites

A fully functionnal indi driver dev environment c.f. [official documentation](https://docs.indilib.org/drivers/basics/project-setup.html)

## Build and install

```sh
mkdir -p build
cd build
cmake -DCMAKE_INSTALL_PREFIX=/usr -DCMAKE_BUILD_TYPE=Debug ../
make
sudo make install
```

or 

```
./make-install.sh
```

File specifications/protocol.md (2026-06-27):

# Com protocol

In this scenario a flat panel is made of two things
- A light panel with variable brightness
- A motorized cover

The firmware updates the state of the flat panel upon instructions of the (ASCOM or INDI) driver. The communication protocol is serial based. The serial connection is established via USB.  

## Messages 

The protocol is thus message based.
- Both the driver and the flat panel (the firmware) exchange single-line messages terminated by '\n'.
- A message is structured as `TYPE:PAYLOAD`, where `TYPE` is one of `COMMAND`, `RESULT`, or `ERROR`, and `PAYLOAD` may include alphanumeric characters, spaces, and `@` separators.

The **driver emits** and the **firmware handles** incoming `COMMAND` messages. A command message is structured as:

- `COMMAND:NAME[@ARGS]` 

where `NAME` is `[A-Z_]+` and `ARGS` may be optional or mandatory depending on the command. For example, in `COMMAND:BRIGHTNESS_SET@ARGS` the `ARGS` are required and represent a single integer value.

The firmware then responds with:
- `RESULT:CMD_NAME@VALUE` when the operation succeeds
- `ERROR:ERR_MESSAGE@DETAILS` when the operation fails

In a nutshell

     -----------------                           ------------
    |                 |                         |            |
    |      Driver     | COMMAND:CMD_NAME[@ARGS] | Flat Panel |
    | (ASCOM or INDI) | --------------------->  | (firmware) |
    |                 | <---------------------  |            |
     -----------------  RESULT:CMD_NAME@VALUE    ------------
                                or
                        ERROR:ERR_MESSAGE@DETAILS

### Command summary
Allowed commands are:
- `COMMAND:PING` — no args, responds with `RESULT:PING@PONG`
- `COMMAND:INFO` — no args, responds with firmware info string
- `COMMAND:VERSION` — no args, responds with firmware version string
- `COMMAND:MAX_BRIGHTNESS` — no args, responds with maximum brightness value
- `COMMAND:BRIGHTNESS_GET` — no args, responds with current brightness value
- `COMMAND:BRIGHTNESS_SET@{value}` — sets brightness and responds with the new value
- `COMMAND:BRIGHTNESS_RESET` — resets brightness to 0
- `COMMAND:COVER_GET_STATE` — returns current cover state
- `COMMAND:COVER_OPEN` — opens the cover
- `COMMAND:COVER_CLOSE` — closes the cover
- `COMMAND:COVER_CALIBRATION_RUN` — runs servo calibration
- `COMMAND:COVER_CALIBRATION_GET` — returns calibration parameters
- `COMMAND:DISCONNECT` — acknowledges disconnection

### Examples
- `COMMAND:PING` → `RESULT:PING@PONG`
- `COMMAND:BRIGHTNESS_SET@100` → `RESULT:BRIGHTNESS_SET@100`
- `COMMAND:COVER_GET_STATE` → `RESULT:COVER_GET_STATE@OPEN`

## Command Details 

### Ping 

- Incoming message :  `COMMAND:PING`
- Args             :  Ignored
- Serial response  :  `RESULT:PING@PONG`
- Serial error     :  Never 
  
### Info 

- Incoming message : `COMMAND:INFO`
- Args             : Ignored
- Serial response  : `RESULT:INFO@{RESULT_INFO}`, where {RESULT_INFO} is the value of the firmware information, e.g. `Le Télescope - Ivry sur Seine - Flat Panel Firmware v1.0`.
- Serial error     : Never 

### Version

- Incoming message : `COMMAND:VERSION`
- Args             :  Ignored
- Serial response  : `RESULT:VERSION@{full_version}`, where {full_version} is the firmware semantic version including panel type and git revision, e.g. `1.0.0.el_panel.<Git Revision>` or `1.0.0.led_panel.<Git Revision>`.
- Serial error     : Never 

### Get Max Brightness

- Incoming message : `COMMAND:MAX_BRIGHTNESS`
- Args             :  Ignored
- Serial response  : `RESULT:MAX_BRIGHTNESS@{MAX_BRIGHTNESS}`, where {MAX_BRIGHTNESS} is the maximum brightness supported by the panel type.
- Serial error     : Never 

### Get Brightness

- Incoming message : `COMMAND:BRIGHTNESS_GET`
- Args             : Ignored
- Serial response  : `RESULT:BRIGHTNESS_GET@{brightness}`, where {brightness} is the current value of the brightness of the panel, as an (int), ex: 50.
- Serial error     : Never

### Set Brightness

- Incoming message : `COMMAND:BRIGHTNESS_SET@{desired_value}`
- Args             : **(uint)** desired_value
- Serial response  : `RESULT:BRIGHTNESS_SET@{panel.brightness}`, where {panel.brightness} is the value of the  brightness member after being set, as an (int).
- Serial error     : Errors in three cases
  - {desired_value} not parsable as int => `INVALID_BRIGHTNESS@Wanted brightness {desired_value} is not a number`
  - {desired_value} <0                  => `INVALID_BRIGHTNESS@Wanted brightness {desired_value} is negative`
  - {desired_value} >  MAX_BRIGHTNESS   => `INVALID_BRIGHTNESS@Wanted brightness {desired_value} is bigger than max allowed value 1023`

### Reset brightness

- Incoming message : `COMMAND:BRIGHTNESS_RESET`
- Args             : Ignored
- Serial response  : `RESULT:BRIGHTNESS_RESET@{0}`
- Serial error     : Never

### Get cover state 

- Incoming message : `COMMAND:COVER_GET_STATE`
- Args             : Ignored
- Serial response  : `RESULT:COVER_GET_STATE@{panel.cover}`, where panel.cover is string human readable translation of the current cover state. Possible values are in [**OPEN**, **OPENING**, **CLOSING**, **CLOSED**]
- Serial error     : Never

### Open cover

- Incoming message : `COMMAND:COVER_OPEN`
- Args             : Ignored
- Serial response  : `RESULT:COVER_OPEN@OK`
- Serial error     : If panel is not calibrated => `ERROR:SERVO_NOT_CALIBRATED@Run command COVER_CALIBRATION_RUN first`

### Close cover

- Incoming message : `COMMAND:COVER_CLOSE`
- Args             : Ignored
- Serial response  : `RESULT:COVER_CLOSE@OK`
- Serial error     : If panel is not calibrated => `ERROR:SERVO_NOT_CALIBRATED@Run command COVER_CALIBRATION_RUN first`

### Run calibration

- Incoming message : `COMMAND:COVER_CALIBRATION_RUN`
- Args             :  Ignored
- Serial response  : `RESULT:COVER_CALIBRATION_RUN@OK`
- Serial error     : Never 

WARNING: Disconnect the right arm from the servo before running the calibration

### Get calibration

- Incoming message : `COMMAND:COVER_CALIBRATION_GET`
- Args             :  Ignored
- Serial response  : `RESULT:COVER_CALIBRATION_GET@slope={panel.calibration.slope} - intercept={panel.calibration.intercept}`
- Serial error     : if panel is not calibrated => `ERROR:SERVO_NOT_CALIBRATED@Run command COVER_CALIBRATION_RUN first`

### Disconnect

- Incoming message : `COMMAND:DISCONNECT`
- Args             :  Ignored
- Serial response  : `RESULT:DISCONNECT@OK`
- Serial error     : Never

### Unknown commands

This one is a special command that is not meant to be called. It is in fact the result of an unknown command sent to the firmware.

- Incoming message : Any message not in the previously mentioned ones.
- Args             : Ignored
- Serial response  : Never
- Serial error     : `ERROR:INVALID_COMMAND@Allowed commands PING, INFO, VERSION, MAX_BRIGHTNESS, BRIGHTNESS_GET, BRIGHTNESS_SET, BRIGHTNESS_RESET, COVER_GET_STATE, COVER_OPEN, COVER_CLOSE, COVER_CALIBRATION_RUN, COVER_CALIBRATION_GET, DISCONNECT` (always)

## Specific error cases

The firmware may emit error messages not related to a specific command.

- If the driver/client serializes a string that is not parsable as a message, the firmware should respond with `ERROR:INVALID_INCOMING_MESSAGE@Allowed messages are TYPE:MESSAGE`

- If the driver/client emits a valid message that is not a command, the firmware should respond with `ERROR:INVALID_INCOMING_MESSAGE_TYPE@Allowed types COMMAND`

- If the driver/client emits an unknown command, i.e. one not in this list, the firmware should respond with `ERROR:INVALID_COMMAND@Allowed commands PING, INFO, VERSION, MAX_BRIGHTNESS, BRIGHTNESS_GET, BRIGHTNESS_SET, BRIGHTNESS_RESET, COVER_GET_STATE, COVER_OPEN, COVER_CLOSE, COVER_CALIBRATION_RUN, COVER_CALIBRATION_GET, DISCONNECT`, c.f. [unknown "commands"](#unknown-commands) above

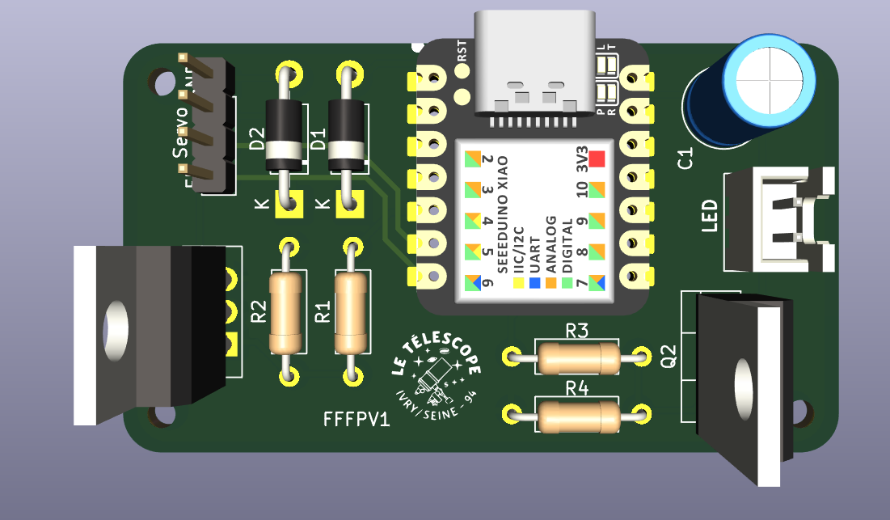
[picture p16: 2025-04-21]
electronics/fffpv1-5V-LEDs/ascom-flat-panel/screenshot_pcb.png

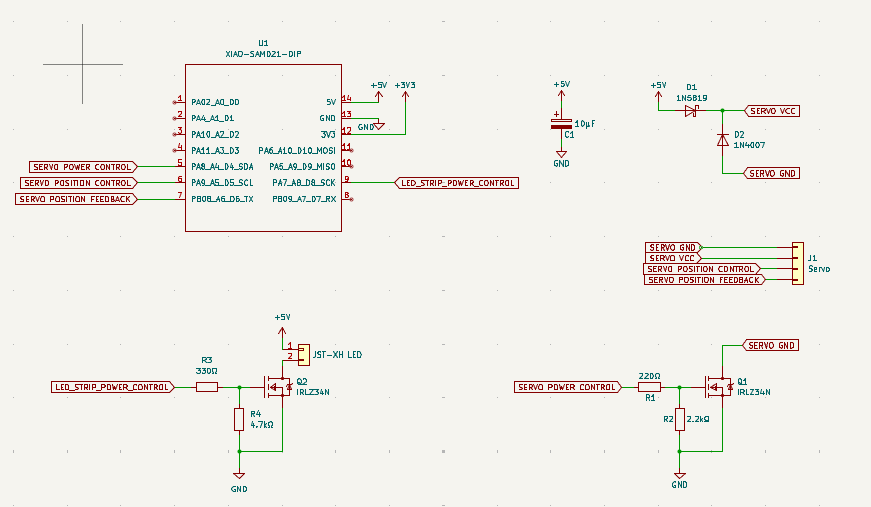
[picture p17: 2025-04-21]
electronics/fffpv1-3V-LEDs/ascom-flat-panel/screenshot.png

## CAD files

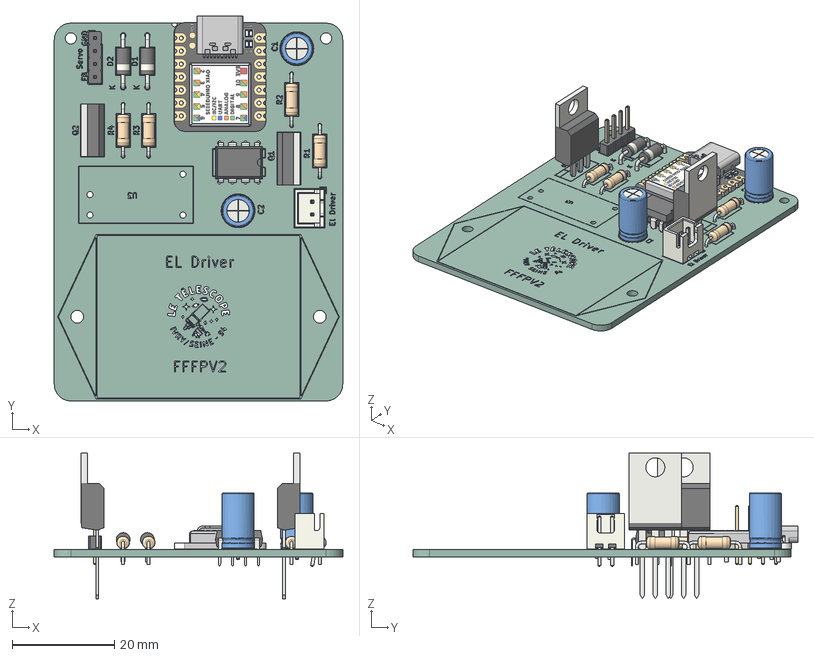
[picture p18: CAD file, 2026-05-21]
electronics/fffpv2_el_panel/ascom-flat-panel/ascom-flat-panel.step
56.5 x 75.4 x 28.5 mm
JST_XH_B2B-XH-A_1x02_P2.50mm_Vertical
D_DO-41_SOD81_P10.16mm_Horizontal x 2
DIP-8_W7.62mm
R_Axial_DIN0207_L6.3mm_D2.5mm_P10.16mm_Horizontal x 4
TO-220-3_Vertical x 2
C_Radial_D6.3mm_H11.0mm_P2.50mm x 2
PinHeader_1x04_P2.54mm_Vertical
ascom-flat-panel_silkscreen x 2
ascom-flat-panel_PCB

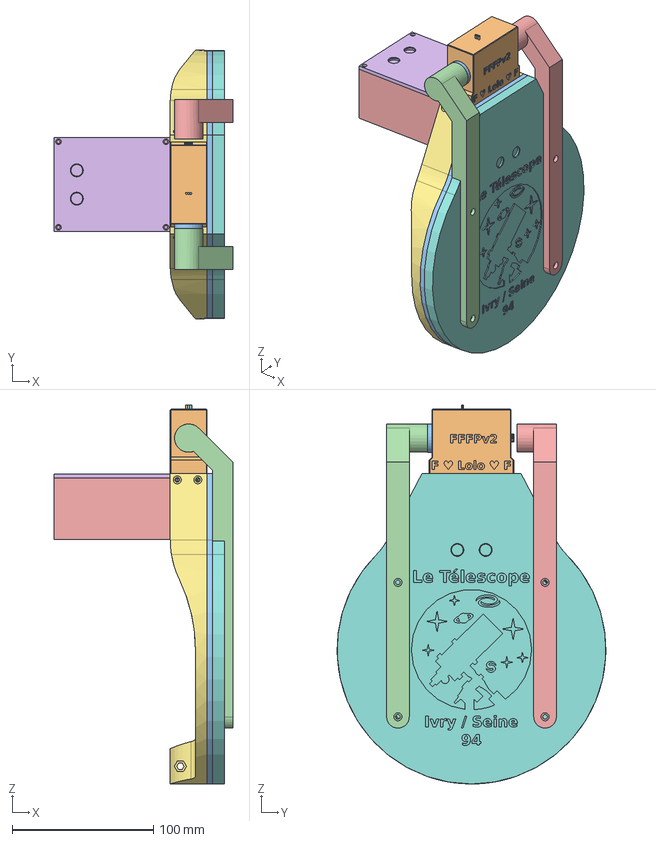
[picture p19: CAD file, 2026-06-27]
models/fffpv2-160mm_el_panel_diam.FCStd
126.2 x 190.0 x 267.9 mm
Servo_Box_Base
Servo_Box_Cover
Bushing
Servo DSS-M15S
Servo DSS-M15S001
Servo DSS-M15S002
Servo DSS-M15S003
Servo DSS-M15S004
Servo DSS-M15S005
Servo DSS-M15S006
Servo DSS-M15S007
Servo DSS-M15S008
Lid
Corps001
Panel_body
Diffuser
EL_panel
Cover
Right_arm
Left_Arm

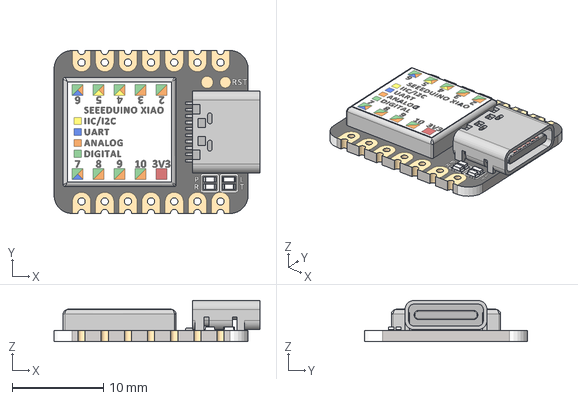
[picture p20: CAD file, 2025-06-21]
electronics/fffpv2_el_panel/ascom-flat-panel/Seeeduino XIAO SAMD21 v4.step
22.6 x 17.9 x 4.51 mm

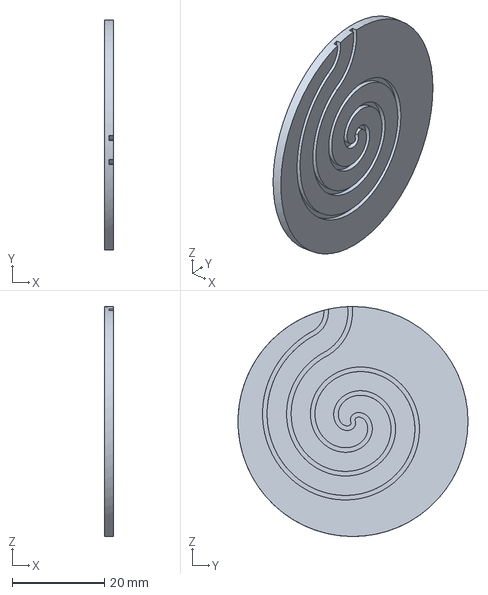
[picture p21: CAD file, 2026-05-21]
models/EpreuveSpirale.FCStd
2.00 x 50.0 x 50.0 mm

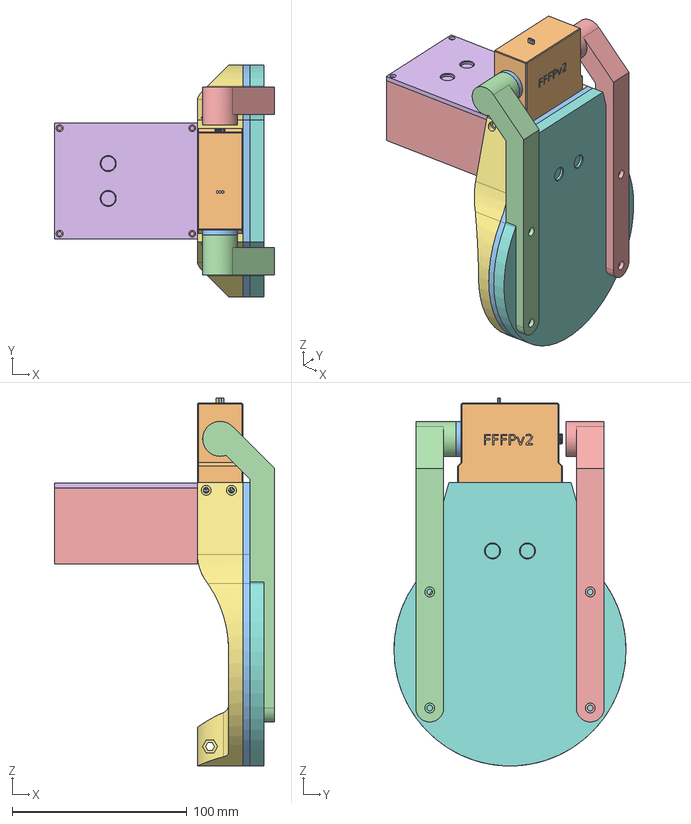
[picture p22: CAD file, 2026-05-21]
models/fffpv2-XXXmm_el_panel_diam_test_scaling.FCStd
126.2 x 133.0 x 210.9 mm
Servo_Box_Base
Servo_Box_Cover
Bushing
Servo DSS-M15S
Servo DSS-M15S001
Servo DSS-M15S002
Servo DSS-M15S003
Servo DSS-M15S004
Servo DSS-M15S005
Servo DSS-M15S006
Servo DSS-M15S007
Servo DSS-M15S008
Lid
Corps001
Panel_body
Diffuser
EL_panel
Cover
Right_arm
Left_Arm

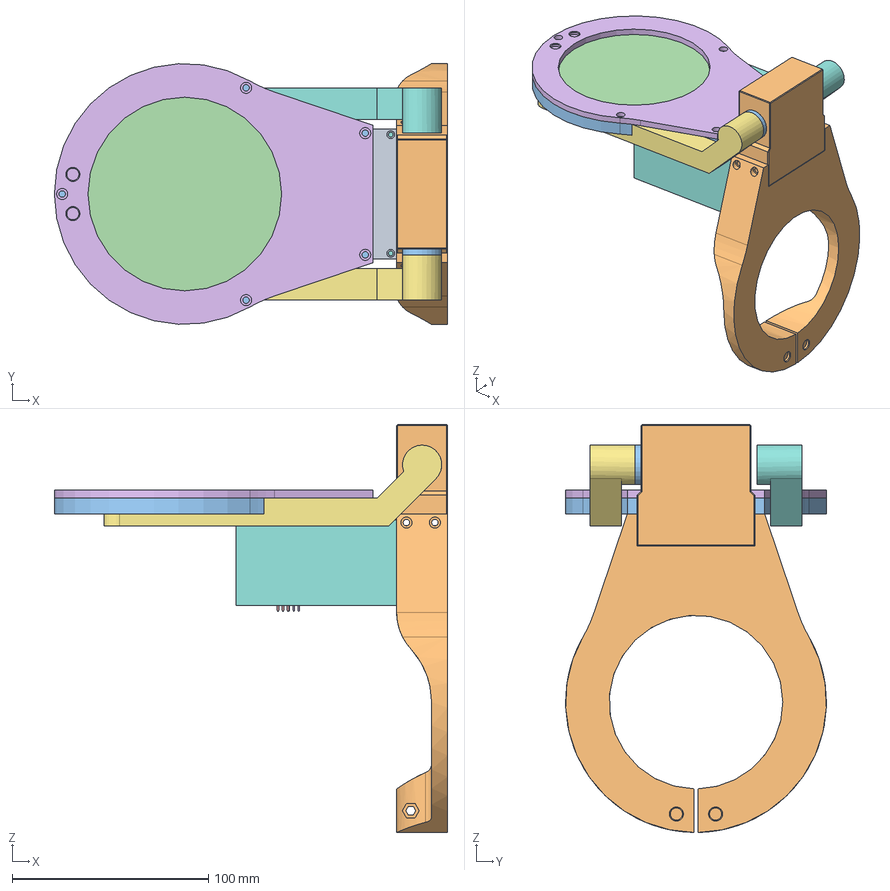
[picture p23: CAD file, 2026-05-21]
models/fffpv2-110mm_el_panel_diam.FCStd
200.5 x 133.0 x 208.0 mm
Servo_Box_Base
Servo_Box_Cover
Bushing
JST_XH_B2B-XH-A_1x02_P2.50mm_Vertical002
D_DO-41_SOD81_P10.16mm_Horizontal004
DIP-8_W7.62mm001
R_Axial_DIN0207_L6.3mm_D2.5mm_P10.16mm_Horizontal008
TO-220-3_Vertical004
TO-220-3_Vertical005
D_DO-41_SOD81_P10.16mm_Horizontal005
R_Axial_DIN0207_L6.3mm_D2.5mm_P10.16mm_Horizontal009
R_Axial_DIN0207_L6.3mm_D2.5mm_P10.16mm_Horizontal010
R_Axial_DIN0207_L6.3mm_D2.5mm_P10.16mm_Horizontal011
C_Radial_D6.3mm_H11.0mm_P2.50mm003
C_Radial_D6.3mm_H11.0mm_P2.50mm004
PinHeader_1x04_P2.54mm_Vertical002
ascom-flat-panel_silkscreen162
ascom-flat-panel_silkscreen163
ascom-flat-panel_silkscreen164
ascom-flat-panel_silkscreen165
ascom-flat-panel_silkscreen166
ascom-flat-panel_silkscreen167
ascom-flat-panel_silkscreen168
ascom-flat-panel_silkscreen169
ascom-flat-panel_silkscreen170
ascom-flat-panel_silkscreen171
ascom-flat-panel_silkscreen172
ascom-flat-panel_silkscreen173
ascom-flat-panel_silkscreen174
ascom-flat-panel_silkscreen175
ascom-flat-panel_silkscreen176
ascom-flat-panel_silkscreen177
ascom-flat-panel_silkscreen178
ascom-flat-panel_silkscreen179
ascom-flat-panel_silkscreen180
ascom-flat-panel_silkscreen181
ascom-flat-panel_silkscreen182
ascom-flat-panel_silkscreen183
ascom-flat-panel_silkscreen184
ascom-flat-panel_silkscreen185
ascom-flat-panel_silkscreen186
ascom-flat-panel_silkscreen187
ascom-flat-panel_silkscreen188
ascom-flat-panel_silkscreen189
ascom-flat-panel_silkscreen190
ascom-flat-panel_silkscreen191
ascom-flat-panel_silkscreen192
ascom-flat-panel_silkscreen193
ascom-flat-panel_silkscreen194
ascom-flat-panel_silkscreen195
ascom-flat-panel_silkscreen196
ascom-flat-panel_silkscreen197
ascom-flat-panel_silkscreen198
ascom-flat-panel_silkscreen199
ascom-flat-panel_silkscreen200
ascom-flat-panel_silkscreen201
ascom-flat-panel_silkscreen202
ascom-flat-panel_silkscreen203
ascom-flat-panel_silkscreen204
ascom-flat-panel_silkscreen205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

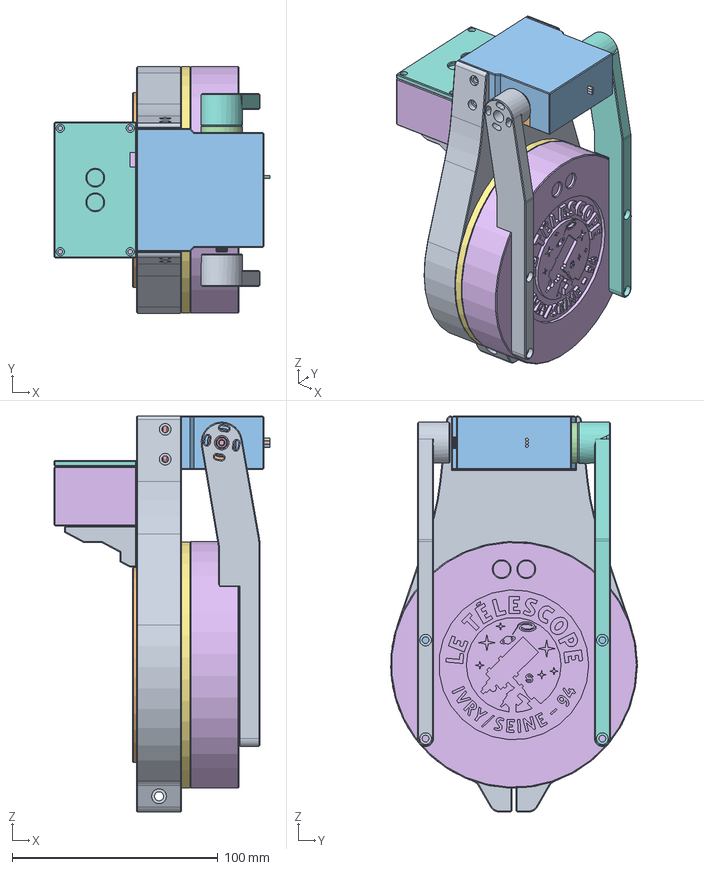
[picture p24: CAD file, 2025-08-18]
models/fffpv1-100mm_led_pan_diam.FCStd
104.9 x 120.0 x 192.6 mm
Corps
Bague
Led Panel001
Spacer-diffuser001
Diffuser001
Corps001
Cover001
bras_droit
bras_gauche
Servo_Box_Base
Servo_Box_Cover
Bushing
Servo DSS-M15S
Servo DSS-M15S001
Servo DSS-M15S002
Servo DSS-M15S003
Servo DSS-M15S004
Servo DSS-M15S005
Servo DSS-M15S006
Servo DSS-M15S007
Servo DSS-M15S008
D_DO-41_SOD81_P10.16mm_Horizontal
R_Axial_DIN0207_L6.3mm_D2.5mm_P10.16mm_Horizontal
R_Axial_DIN0207_L6.3mm_D2.5mm_P10.16mm_Horizontal001
R_Axial_DIN0207_L6.3mm_D2.5mm_P10.16mm_Horizontal002
TO-220-3_Vertical
D_DO-41_SOD81_P10.16mm_Horizontal001
R_Axial_DIN0207_L6.3mm_D2.5mm_P10.16mm_Horizontal003
TO-220-3_Vertical001
C_Radial_D6.3mm_H11.0mm_P2.50mm
JST_XH_B2B-XH-A_1x02_P2.50mm_Vertical
PinHeader_1x04_P2.54mm_Vertical
ascom-flat-panel_PCB
Lid
Bracket

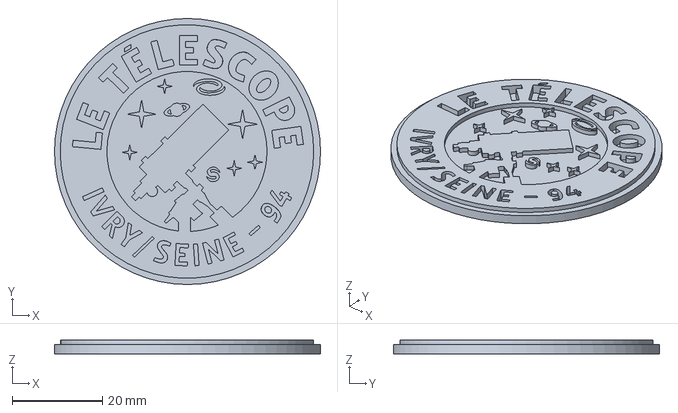
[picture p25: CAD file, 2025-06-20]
models/Logo.FCStd
58.8 x 58.8 x 3.00 mm

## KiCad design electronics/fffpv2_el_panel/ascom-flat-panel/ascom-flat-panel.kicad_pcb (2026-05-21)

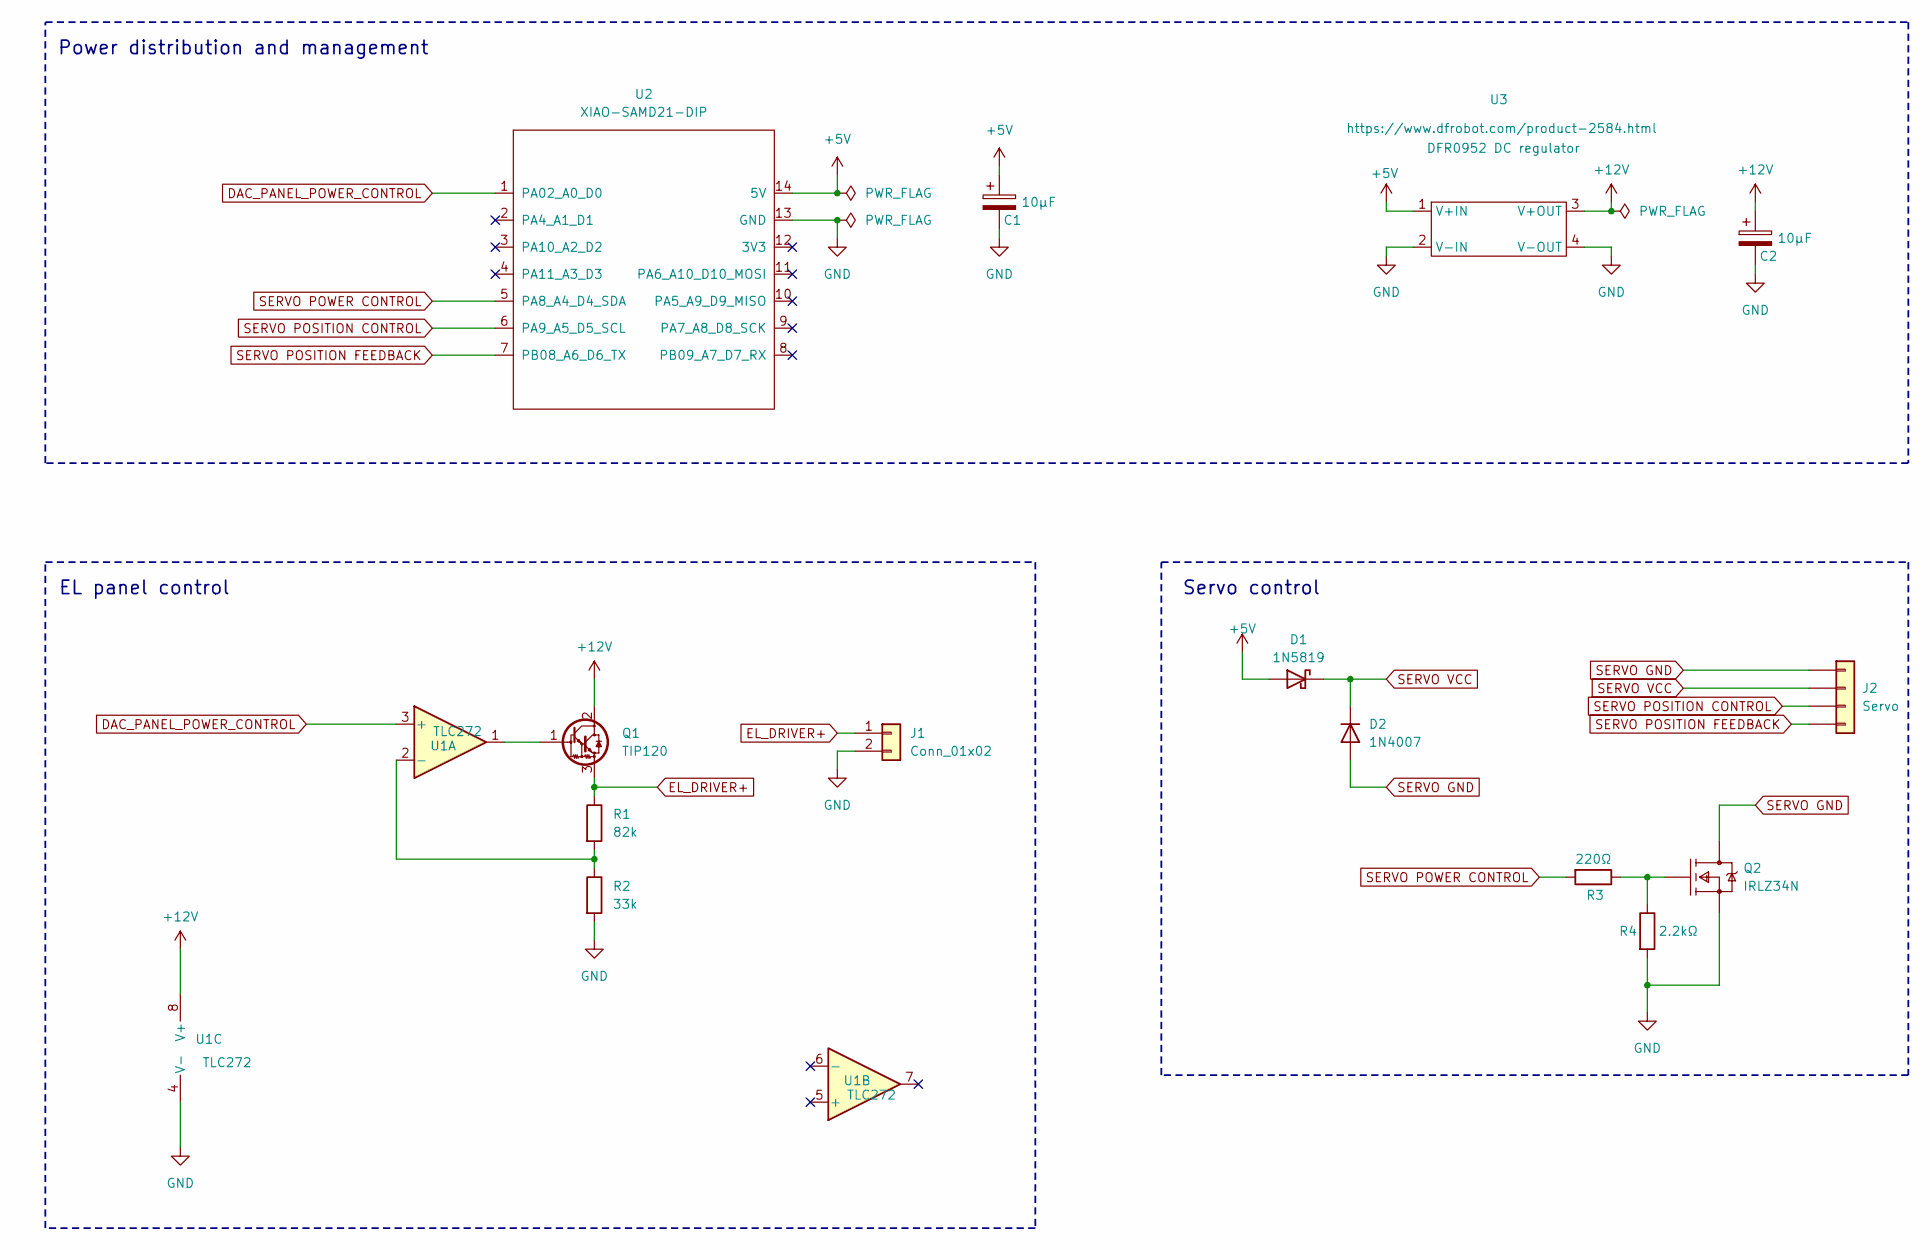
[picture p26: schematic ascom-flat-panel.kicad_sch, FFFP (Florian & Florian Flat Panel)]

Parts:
C1, C2: 10µF; C_Radial_D6.3mm_H11.0mm_P2.50mm
D1: 1N5819; D_DO-41_SOD81_P10.16mm_Horizontal
D2: 1N4007; D_DO-41_SOD81_P10.16mm_Horizontal
J1: Conn_01x02; JST_XH_B2B-XH-A_1x02_P2.50mm_Vertical
J2: Servo; PinHeader_1x04_P2.54mm_Vertical
Q1: TIP120; TO-220-3_Vertical
Q2: IRLZ34N; TO-220-3_Vertical; breakdown voltage drain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 60 V; current rating 32 A; mouser part number 512-FQP30N06L; digikey description MOSFET N-CH 60V 32A TO-220
R1: 82k; R_Axial_DIN0207_L6.3mm_D2.5mm_P10.16mm_Horizontal
R2: 33k; R_Axial_DIN0207_L6.3mm_D2.5mm_P10.16mm_Horizontal
R3: 220Ω; R_Axial_DIN0207_L6.3mm_D2.5mm_P10.16mm_Horizontal
R4: 2.2kΩ; R_Axial_DIN0207_L6.3mm_D2.5mm_P10.16mm_Horizontal
U1: TLC272; DIP-8_W7.62mm
U2: XIAO-SAMD21-DIP
U3: DFR052 DC regulator

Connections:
+5V: C1.1, D1.2 (A), U2.14 (5V), U3.1 (V+IN)
+12V: C2.1, Q1.2 (C), U1.8 (V+), U3.3 (V+OUT)
DAC_PANEL_POWER_CONTROL: U1.3 (+), U2.1 (PA02_A0_D0)
EL_DRIVER+: J1.1, Q1.3 (E), R1.1; also elsewhere on the board
GND: C1.2, C2.2, J1.2, Q2.3 (S), R2.2, R4.2, U1.4 (V-), U2.13 (GND), U3.2 (V-IN), U3.4 (V-OUT); also elsewhere on the board
unnamed: Q1.1 (B), U1.1
unnamed: Q2.1 (G), R3.1, R4.1
unnamed: R1.2, R2.1, U1.2 (-)
SERVO GND: D2.2 (A), J2.1, Q2.2 (D)
SERVO POSITION CONTROL: J2.3, U2.6 (PA9_A5_D5_SCL)
SERVO POSITION FEEDBACK: J2.4, U2.7 (PB08_A6_D6_TX)
SERVO POWER CONTROL: R3.2, U2.5 (PA8_A4_D4_SDA)
SERVO VCC: D1.1 (K), D2.1 (K), J2.2

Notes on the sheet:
Servo control
Power distribution and management
EL panel control

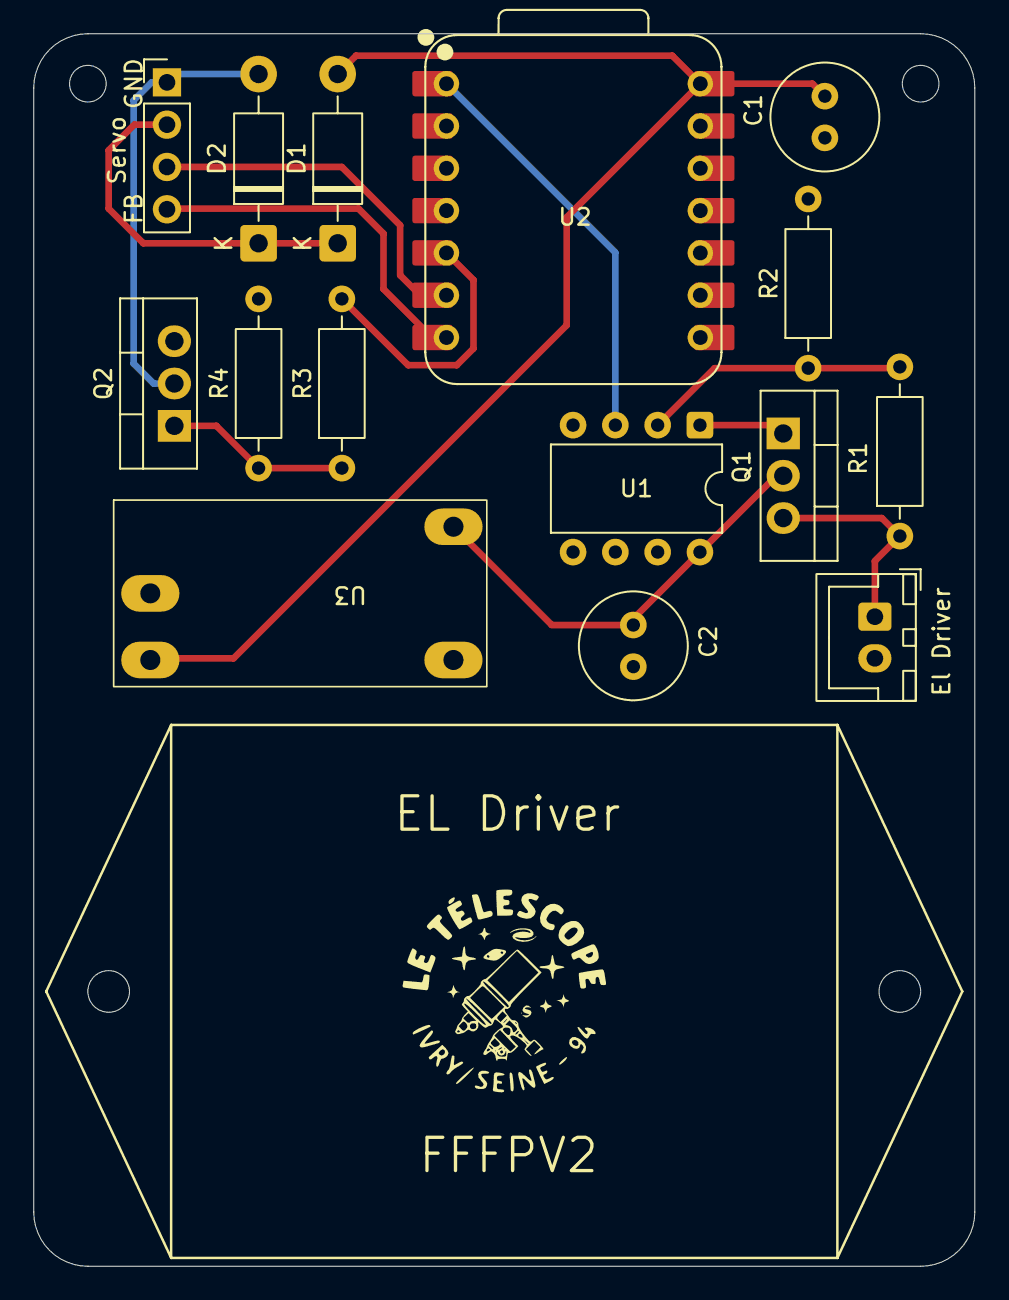
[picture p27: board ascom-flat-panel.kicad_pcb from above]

Board: 2 copper layers, 56.5 x 74.0 mm, 15 parts (0 on the bottom side), 13 nets.

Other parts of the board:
El Driver: Conn_01x02; JST_XH_B2B-XH-A_1x02_P2.50mm_Vertical

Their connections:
EL_DRIVER+: El Driver.1; also elsewhere on the board
GND: El Driver.2; also elsewhere on the board

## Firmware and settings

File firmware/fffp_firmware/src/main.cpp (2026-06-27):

/*
 * fffp_firmware/main.cpp
 * Copyright (C) 2025 - Present, Le Télescope - Ivry sur Seine - All Rights Reserved
 * Licensed under the MIT License. See the accompanying LICENSE file for terms.
 *
 * Description: Arduino firmware for an ASCOM driven automated and motorised flat panel
 *
 * Authors:
 * - Florian Thibaud
 * - Florian Gautier
 *
 * Principle: In this scenario a flat panel is made of two things
 * - A light panel with variable brightness
 * - A motorized cover
 *
 * The firmware updates the state of the flat panel upon instructions of the ASCOM driver. The communication protocol
 * is serial based. The serial connection is established via USB. Here is a a summary of the protocol
 *  - Both the driver and the flat panel (and hence this firmware) exchange single line messages.
 *  - A message is structured as TYPE:MESSAGE, where TYPE is in "COMMAND, RESULT, ERROR" and MESSAGE is alaphanumerical with spaces and "@"
 *
 * This firware only handles incoming "COMMAND" messages. This kind of message is stuctured as
 *
 * COMMAND:NAME[@ARGS]
 *
 * where NAME is [A-Z_]+ and ARGS are optional and their nature may depend on the command. For instance for a COMMAND:BRIGHTNESS_SET@ARGS message the ARGS
 * are mandatory and should consists of a single "int"
 *
 * This firware reponse with
 * - either a RESULT:CMD_NAME@VALUE  if operation succeeded
 * - or an ERROR:ERR_MESSAGE@DETAILS if anything went wrong
 *
 * In a nutshell
 *  --------------                           ------------
 * |              |                         |            |
 * |              | COMMAND:CMD_NAME[@ARGS] | Flat Panel |
 * | ASCOM driver | --------------------->  | (firmware) |
 * |              | <---------------------  |            |
 * ---------------  RESULT:CMD_NAME@VALUE    ------------
 *                          or
 *                 ERROR:ERR_MESSAGE@DETAILS
 *
 * Allowed commands are:
 * - COMMAND:PING
 * - COMMAND:INFO
 * - COMMAND:BRIGHTNESS_GET
 * - COMMAND:BRIGHTNESS_SET@{(int) DESIRED_VALUE}
 * - COMMAND:BRIGHTNESS_RESET
 * - COMMAND:COVER_GET_STATE
 * - COMMAND:COVER_OPEN
 * - COMMAND:COVER_CLOSE
 * - COMMAND:COVER_CALIBRATION_RUN
 * - COMMAND:COVER_CALIBRATION_GET
 *
 * The protocol, the implementation of both the ASCOM driver and this firmware, the electronics and the 3D models
 * are heavily inspired by the the work  of Dark Sky Geek (https://github.com/jlecomte/) especially
 * - https://github.com/jlecomte/ascom-flat-panel
 * - https://github.com/jlecomte/ascom-wireless-flat-panel
 * - https://github.com/jlecomte/ascom-telescope-cover-v2
 *
 */

#include <Servo.h>
#include <FlashStorage.h>
#include <Adafruit_SleepyDog.h>
#include <Samd21_PulseWidthModulation.h>
#include <FF_FlatPanel.h>

#if !defined FFFP_TYPE_EL_PANEL && !defined FFFP_TYPE_LED_PANEL 
    #error "Light panel type undefined. FFFP_TYPE_LED_PANEL or FFFP_TYPE_EL_PANEL must be set in the build settings"
#endif

/************************************************
 *     Types, Objects, and data structures      *
 ***********************************************/

/*
 * Flat panel state related types/data structures
 */

// Represents the state of the flat panel cover. The cover is either open, opening, closing or closed.
typedef enum
{
  OPENING,
  OPEN,
  CLOSING,
  CLOSED,
} cover_state_t;

// Represents the state of the flat panel servo configuration.
//
// This configuration will be stored/retreived from flash memory. Hence the magic number, to check if the retrieved
// configuration is garbage or actual configuraton that was correctly stored previously.
typedef struct
{
  // Magic
  unsigned int magic_number;
  double slope;
  double intercept;
} servo_cal_state_t;

// Represents the panel(led and cover) state.
// Could ben restructured but this would bring layers of inderiction and less readability
typedef struct
{
  uint32_t brightness;
  int servo_position; // Holds the targeted servo position (maybe different from the actual one)
  uint32_t position_convergence_counter;
  unsigned long last_step_time;
  unsigned long last_cal_check_time;
  cover_state_t cover;
  servo_cal_state_t calibration;
} panel_state_t;

/************************************************
 *                  Constants                   *
 ***********************************************/

/*
 * Messages parser related constants
 */

#if ! defined FFFP_FIRMWARE_VERSION
#error "FFFP_FIRMWARE_VERSION not defined"
#endif
#if ! defined FFFP_GIT_REV
#error "FFFP_GIT_REV not defined"
#endif
#if defined FFFP_TYPE_EL_PANEL
constexpr auto FFFP_PANEL_TYPE = ".el_panel-";
#elif defined FFFP_TYPE_LED_PANEL 
constexpr auto FFFP_PANEL_TYPE = ".led_panel-";
#else
#error "Light panel type undefined. FFFP_TYPE_LED_PANEL or FFFP_TYPE_EL_PANEL must be set in the build settings"
#endif

constexpr auto MESSAGE_END_DELIMITER = "\n";
constexpr auto TYPE_COMMAND_SEPARATOR = ":";
constexpr auto COMMAND_ARGS_SEPARATOR = "@";

/*
 * Available commands (names), custom results, and errors
 */
constexpr auto COMMAND_MSG_TYPE = "COMMAND";
constexpr auto RESULT_MSG_TYPE = "RESULT";
constexpr auto ERROR_MSG_TYPE = "ERROR";

constexpr auto COMMAND_PING = "PING";
constexpr auto RESULT_PING = "PONG";

constexpr auto COMMAND_INFO = "INFO";
constexpr auto RESULT_INFO_MSG_START = "Le Telescope - Ivry sur Seine - Flat Panel Firmware v";
#if defined FFFP_TYPE_EL_PANEL
constexpr auto RESULT_INFO_MSG_MIDDLE_PART = ". Built for an EL panel. Git Revision: ";
#elif defined FFFP_TYPE_LED_PANEL 
constexpr auto RESULT_INFO_MSG_MIDDLE_PART = ". Built for an LED panel. Git Revision: ";
#else
#error "Light panel type undefined. FFFP_TYPE_LED_PANEL or FFFP_TYPE_EL_PANEL must be set in the build settings"
#endif

constexpr auto COMMAND_VERSION = "VERSION";
constexpr auto COMMAND_MAX_BRIGHTNESS = "MAX_BRIGHTNESS";
constexpr auto COMMAND_BRIGHTNESS_GET = "BRIGHTNESS_GET";
constexpr auto COMMAND_BRIGHTNESS_SET = "BRIGHTNESS_SET";
constexpr auto COMMAND_BRIGHTNESS_RESET = "BRIGHTNESS_RESET";

constexpr auto COMMAND_COVER_GET_STATE = "COVER_GET_STATE";
constexpr auto RESULT_COVER_GET_STATE_OPEN = "OPEN";
constexpr auto RESULT_COVER_GET_STATE_OPENING = "OPENING";
constexpr auto RESULT_COVER_GET_STATE_CLOSED = "CLOSED";
constexpr auto RESULT_COVER_GET_STATE_CLOSING = "CLOSING";

constexpr auto COMMAND_COVER_OPEN = "COVER_OPEN";
constexpr auto RESULT_COVER_OPEN = "OK";
constexpr auto COMMAND_COVER_CLOSE = "COVER_CLOSE";
constexpr auto RESULT_COVER_CLOSE = "OK";
constexpr auto COMMAND_COVER_CALIBRATION_RUN = "COVER_CALIBRATION_RUN";
constexpr auto RESULT_COVER_CALIBRATION_RUN = "OK";
constexpr auto COMMAND_COVER_CALIBRATION_GET = "COVER_CALIBRATION_GET";

constexpr auto COMMAND_DISCONNECT = "DISCONNECT";
constexpr auto RESULT_DISCONNECT = "OK";

constexpr auto COMMAND_UNKNOWN = "UNKNOWN";

constexpr auto ERROR_INVALID_INCOMING_MESSAGE = "INVALID_INCOMING_MESSAGE@Allowed messages are TYPE:MESSAGE:[@PARAMETER]";
constexpr auto ERROR_INVALID_INCOMING_MESSAGE_TYPE = "INVALID_INCOMING_MESSAGE_TYPE@Allowed types COMMAND";
constexpr auto ERROR_INVALID_COMMAND = "INVALID_COMMAND@Allowed commands PING, INFO, BRIGHTNESS_GET, BRIGHTNESS_SET, BRIGHTNESS_RESET, COVER_GET_STATE, COVER_OPEN, COVER_CLOSE, COVER_CALIBRATION_RUN, COVER_CALIBRATION_GET, DISCONNECT";
constexpr auto ERROR_WANTED_BRIGHTNESS_MSG_START = "INVALID_BRIGHTNESS@Wanted brightness {";
constexpr auto ERROR_WANTED_BRIGHTNESS_NAN_MSG_END = "} is not a number.";
constexpr auto ERROR_WANTED_BRIGHTNESS_NEGATIVE_MSG_END = "} is negative.";
#if defined FFFP_TYPE_EL_PANEL
constexpr auto ERROR_WANTED_BRIGHTNESS_TOO_BIG_MSG_END = "} is bigger than max allowed value 1023.";
#elif defined FFFP_TYPE_LED_PANEL 
constexpr auto ERROR_WANTED_BRIGHTNESS_TOO_BIG_MSG_END = "} is bigger than max allowed value 2047.";
#else
#error "Light panel type undefined. FFFP_TYPE_LED_PANEL or FFFP_TYPE_EL_PANEL must be set in the build settings"
#endif

constexpr auto ERROR_SERVO_NOT_CALIBRATED = "SERVO_NOT_CALIBRATED@Run command COVER_CALIBRATION_RUN first";

#define NB_COMMANDS 13
// Keeps the record of allowed/known commands
const command_t allowed_cmds[NB_COMMANDS] = {{COMMAND_PING, &cmd_ping},
                                                 {COMMAND_INFO, &cmd_info},
                                                 {COMMAND_VERSION, &cmd_version},
                                                 {COMMAND_MAX_BRIGHTNESS, &cmd_max_brightness},
                                                 {COMMAND_BRIGHTNESS_GET, &cmd_brightness_get},
                                                 {COMMAND_BRIGHTNESS_SET, &cmd_brightness_set},
                                                 {COMMAND_BRIGHTNESS_RESET, &cmd_brightness_reset},
                                                 {COMMAND_COVER_GET_STATE, &cmd_cover_get_state},
                                                 {COMMAND_COVER_OPEN, &cmd_cover_open},
                                                 {COMMAND_COVER_CLOSE, &cmd_cover_close},
                                                 {COMMAND_COVER_CALIBRATION_RUN, &cmd_cover_calibration_run},
                                                 {COMMAND_COVER_CALIBRATION_GET, &cmd_cover_calibration_get},
                                                 {COMMAND_DISCONNECT, &cmd_disconnect}};

/*
 * Light panel related constants
 */
constexpr uint32_t MIN_BRIGHTNESS = 0;
#if defined FFFP_TYPE_EL_PANEL
// Seeeduino Xiao DAC max resolution is 10 bit. hence we set max brightness to 2^10-1 = 1023
constexpr uint32_t MAX_BRIGHTNESS = 1023;
constexpr float DAC_RESOLUTION_BITS = 10;
#elif defined FFFP_TYPE_LED_PANEL
// Eventhough we use 16bits register counters for PWM at 20 000 Hz the actual resolution is more 2^11.
// The rationale being that the CPU clock frequency (48 MHz) is the limiting factor here.
// For exemple at 20kHz pwm, there is arout 2500 cpu cycle during a full period. Hence effectively the resolution is at most something aroun 11bit.
// This was validated experimentally. The effective rsolution is just shy aboce 11bit in this case. To be conservative we choose 11bit.
constexpr uint32_t MAX_BRIGHTNESS = 2047;
constexpr float PWM_FREQ = 20000.0f;
#else
#error "Light panel type undefined. FFFP_TYPE_LED_PANEL or FFFP_TYPE_EL_PANEL must be set in the build settings"
#endif


/*
 * DSS-M15S Servo with analog feedback related constants
 */

// MIN and MAX angle are default for "servos".
// Nope 180° for MAX angle is not a mistake. It is really the value one wants here.
// Even though ours can go to 270° those are set using the pulse width MIN and MAX.C.f below.
constexpr int SERVO_MIN_ANGLE = 0;
constexpr int SERVO_MAX_ANGLE = 180; // Yes this is correct. Full amplitude is set with MIN_PW and MAX_PW
// Used to get the proper full range of motion (270°). Used by the servo library to map
// input angles (betwenn 0 and 180) to wanted 0 to 270° "real" wanted angles.
// Those are figures from the  DSS-M15S Servo specifications and depend on the exact servo you are using.
constexpr uint32_t SERVO_MIN_PW = 500;
constexpr uint32_t SERVO_MAX_PW = 2500;

/*
 * Pins assignment. Must be set according to the exact actual wiring.
 * Check KiCad shcematics to check the correct pins
 */

#if defined FFFP_TYPE_EL_PANEL
constexpr unsigned int EL_PANEL_DAC_PIN = A0;
#elif defined FFFP_TYPE_LED_PANEL
constexpr unsigned int LEDSTRIP_PIN = 8;
#else
#error "Light panel type undefined. FFFP_TYPE_LED_PANEL or FFFP_TYPE_EL_PANEL must be set in the build settings"
#endif

constexpr unsigned int SERVO_POWER_PIN = 4;
constexpr unsigned int SERVO_POS_CONTROL_PIN = 5;
constexpr unsigned int SERVO_FEEDBACK_PIN = 6;
/*
 * Misc.
 */
// Value used to determine whether the NVM (Non-Volatile Memory) was written, or we are just reading garbage...
constexpr unsigned int NVM_MAGIC_NUMBER = 0x12345678;

// How long do we wait between each step (loop) in order to achieve the desired speed?
constexpr unsigned long STEP_DELAY_MICROSEC = 30L * 1000; // 30 msec
// How long do we wait between each check (loop) in order to achieve correct blink rate? Blinks twice a sec.
constexpr unsigned long BLINK_DELAY_MILLISEC = 500L;
// How long do wait for convergence at most?
constexpr uint32_t MAX_CONVERGENCE_RETRIES = 5;
// How close we want to be?
constexpr int CONVERGENCE_CRITERIA = 1;

/************************************************
 *             Global/State variables           *
 ***********************************************/

// Holds the panel(led and cover) state.
panel_state_t panel;

// Client used to interact with the servo motor.
Servo servo;

#if defined FFFP_TYPE_LED_PANEL
// Controller to set led brightness
//  We choose PIN 8 as its timer counter is TCC1 wich is a 16bit register that will allow us for the fast PWM and stil above par resolution.
SAMD21_PWM pwm_controller = {LEDSTRIP_PIN, PWM_FREQ, 0};
#endif

// Defines "nvm_store", the actual Flash sotrage where the calibration data will be stored/retrieved
FlashStorage(nvm_store, servo_cal_state_t);

/************************************************
 *              Arduino entrypoints             *
 ***********************************************/
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
void loop()
{

  // First we seek for commands
  receive_commands();

  // Then we check if calibration is needed
  check_for_calibration();

  // Then we update panel cover position if needed
  update_panel_cover();
}

/*
 * Collect incoming serial messages and fires the according commands.
 *
 * If data has arrived through the serial port
 *
 * - Reads a full line, i.e a string that ends with \n
 * - Parse the message and get the command payload
 *    + "Serials" the error message ERROR_INVALID_INCOMING_MESSAGE
 *      if message does not comply with the message structure defined in the protocol TYPE:BODY
 *    + "Serials" the error message ERROR_INVALID_INCOMING_MESSAGE_TYPE) if message is not a command,
 *      i.e, TYPE is not COMMAND
 * - Fires the correct command.
 *   + Each command will serial their own results/errors
 *   + If no matching command is found, the "UNKNOWN" command is fired that "serials" the error message ERROR_INVALID_COMMAND
 */
void receive_commands()
{
  if (Serial.available() > 0)
  {
    String message = Serial.readStringUntil('\n');

    bool error = false;

    auto cmd_payload = get_cmd_payload(message, &error);
    if (error)
    {
      return;
    }

    auto command = get_command_from_payload(cmd_payload);
    command.handle(cmd_payload.args);
  }
}

/*
 * Checks if panel is calibrated and notify (by blinking buil-in led) the users to do so
 */
void check_for_calibration()
{

  if (!is_panel_calibrated())
  {

    unsigned long now = millis();

    if (now - panel.last_cal_check_time < BLINK_DELAY_MILLISEC)
      return;

    int current_state = digitalRead(LED_BUILTIN);
    int toggled_state = current_state == HIGH ? LOW : HIGH;

    digitalWrite(LED_BUILTIN, toggled_state);
    panel.last_cal_check_time = now;
  }
}

/*
 * Updates the servo/cover physical position, if need be, according to the OPENING or CLOSING state of the cover
 *
 * - If the Panel cover is "OPENING", increments the servo position
 *   +  If it reaches SERVO_MAX_ANGLE, try to check MAX_CONVERGENCE_RETRIES times
 *      if it actually reached SERVO_MAX_ANGLE and marks the cover as OPEN
 * - If the Panel cover is "CLOSING", decrements the servo position
 *   +  If it reaches SERVO_MIN_ANGLE, try to check MAX_CONVERGENCE_RETRIES times
 *      if actully reached SERVO_MIN_ANGLE and marks the cover as CLOSED
 * - Updates the "physical" servo postion with the calculated one
 * - Power down the servo il Panel is OPEN or CLOSED
 *
 * Will do nothing if
 * - Panel is not calibrated
 * - Panel is OPEN
 * - Panel is CLOSED
 */
void update_panel_cover()
{
  // We do not move we are not calibrated
  if (!is_panel_calibrated())
    return;
  // We do not move are in a steady state, i.e. either OPEN or CLOSED
  if (panel.cover == OPEN || panel.cover == CLOSED)
    return;

  unsigned long now = micros();
  // We do not move it is too early
  if (now - panel.last_step_time < STEP_DELAY_MICROSEC)
    return;

  panel.last_step_time = now;

  // Ramping up "slowly" target position
  // If LED_PANEL type, panel should seek to reach Max angle when opening.
  // Contrary wise for EL_Panel builds,the servo is on the other arm hence
  // it should seek to reach min angle when opening.
#if defined FFFP_TYPE_EL_PANEL
  if (panel.cover == CLOSING)
#elif defined FFFP_TYPE_LED_PANEL
  if (panel.cover == OPENING)
#endif
  {
    panel.servo_position++;
    if (panel.servo_position >= SERVO_MAX_ANGLE)
    {
      panel.servo_position = SERVO_MAX_ANGLE;
    }
  }
#if defined FFFP_TYPE_EL_PANEL
  else if (panel.cover == OPENING)
#elif defined FFFP_TYPE_LED_PANEL
  else if (panel.cover == CLOSING)
#endif
  {
    panel.servo_position--;
    if (panel.servo_position <= SERVO_MIN_ANGLE)
    {
      panel.servo_position = SERVO_MIN_ANGLE;
    }
  }

  servo.write(panel.servo_position);

  // MAX angle maens servo targets "Closed" position for EL panel type
  // MAX angle means servo targets "Open" position for LED panel type. 
  // Check if we are really there
  if (panel.servo_position == SERVO_MAX_ANGLE)
  {

    int actual_pos = get_current_servo_pos();

    bool has_reached_target = (SERVO_MAX_ANGLE - actual_pos) <= CONVERGENCE_CRITERIA;
    bool too_manmy_retries = panel.position_convergence_counter > MAX_CONVERGENCE_RETRIES;

    if (has_reached_target || too_manmy_retries)
    {
#if defined FFFP_TYPE_EL_PANEL
      panel.cover = CLOSED;
#elif defined FFFP_TYPE_LED_PANEL
      panel.cover = OPEN;
#endif
      panel.position_convergence_counter = 0;
    }
    else
    {
      panel.position_convergence_counter++;
    }
  }

  // MIN Angle mean servo targets "open" position for EL panle type.
  // Min Angle means servo targets "close" position for Led panel type.
  // Check if we are really there
  if (panel.servo_position == SERVO_MIN_ANGLE)
  {

    int actual_pos = get_current_servo_pos();

    bool has_reached_target = (actual_pos - SERVO_MIN_ANGLE) <= CONVERGENCE_CRITERIA;
    bool too_manmy_retries = panel.position_convergence_counter > MAX_CONVERGENCE_RETRIES;

    if (has_reached_target || too_manmy_retries)
    {
#if defined FFFP_TYPE_EL_PANEL
      panel.cover = OPEN;
#elif defined FFFP_TYPE_LED_PANEL
      panel.cover = CLOSED;
#endif
      panel.position_convergence_counter = 0;
    }
    else
    {
      panel.position_convergence_counter++;
    }
  }

  if (panel.cover == OPEN || panel.cover == CLOSED)
  {
    powerDownServo();
  }
}

/************************************************
 *                   Commands                   *
 ***********************************************/

/*
 * Ping command handler.
 *
 * Dummy command that answers PONG to a COMMAND:PING message.
 *
 * Incoming message :  COMMAND:PING
 * Args             :  Ignored
 * Serial response  :  RESULT:PING@PONG
 * Serial error     :  Never
 */
void cmd_ping(const String args)
{
  serialize_result(COMMAND_PING, RESULT_PING);
}

/*
 * Info command handler.
 *
 * This command answers with the version info of the firmware to a COMMAND:INFO message.
 *
 * Incoming message : COMMAND:INFO
 * Args             : Ignored
 * Serial response  : RESULT:INFO@{RESULT_INFO}, where {RESULT_INFO} is the value of the same constant.
 * Serial error     : Never
 */
void cmd_info(const String args)
{
  String result_info_msg = String(RESULT_INFO_MSG_START) + full_version() + RESULT_INFO_MSG_MIDDLE_PART + FFFP_GIT_REV;
  serialize_result(COMMAND_INFO, result_info_msg);
}

/*
 * Info command handler.
 *
 * This command answers with the version info of the firmware to a COMMAND:INFO message.
 *
 * Incoming message : COMMAND:VERSION
 * Args             : Ignored
 * Serial response  : RESULT:VERSION@x.y.z.{el_panel|led_panel}.<Git Revision>.
 * Serial error     : Never
 */
void cmd_version(const String args)
{
  serialize_result(COMMAND_VERSION, full_version());
}

/*
 * "Get Max Brightness" command handler.
 *
 * This command answers with the maximum brightness value to a COMMAND:MAX_BRIGHTNESS message.
 *
 * Incoming message : COMMAND:MAX_BRIGHTNESS
 * Args             : Ignored
 * Serial response  : RESULT:MAX_BRIGHTNESS@{MAX_BRIGHTNESS}, where {MAX_BRIGHTNESS} is the
 *                    constant defined in this file. This depends on the panel type (definition is behind preprocessor directives)
 * Serial error     : Never
 */
void cmd_max_brightness(const String args)
{
  serialize_result(COMMAND_MAX_BRIGHTNESS, String(MAX_BRIGHTNESS));
}
/*
 * "Get Brightness" command handler.
 *
 * This command answers with the current brightness value to a COMMAND:BRIGHTNESS_GET message.
 *
 * Incoming message : COMMAND:BRIGHTNESS_GET
 * Args             : Ignored
 * Serial response  : RESULT:BRIGHTNESS_GET@{panel.brightness}, where {panel.brightness} is the
 *                    current value of the  brightness member of the panle "panle_state_t" struct.
 * Serial error     : Never
 */
void cmd_brightness_get(const String args)
{
  serialize_result(COMMAND_BRIGHTNESS_GET, String(panel.brightness));
}
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

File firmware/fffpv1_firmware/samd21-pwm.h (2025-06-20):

/*
 * samd21-pwm.h
 * Copyright (C) 2025 - Present, Le Télescope - Ivry sur Seine - All Rights Reserved
 * Licensed under the MIT License. See the accompanying LICENSE file for terms.
 *
 * Description: Library for hardware based fast pwm for SAMM21 based boards. 
 * This was tested on a Seeeduino XIAO.
 * 
 * This leverages the 16 bits timers counters to generates fast pulses and allow for "high frequency" PWM. 
 * The lib will fetch automatically wich timer to use according to the wanted output pin. 
 *
 * Not every pin is addressable by a "TCC". Check the specs to know which pin to use. 
 * If a pin uses a "TC" and not a "TCC" this lib will revert back automatically to the 8bit resolution. 
 * Still you will have to set the wanted duty cycle using a 16bit value, the conversion to 8 bit will be made for you by the lib.
 *
 * Just a word of caution: Using a pin with a 16bit register does not guarant you get an effective 16bit resolution.
 * The rationale being that the CPU clock frequency (48 MHz) is the limiting factor here. For exemple at 20kHz pwm, 
 * there is arout 2500 cpu cycle during a full period. Hence effectively the resolution is at most something aroun 11bit. 
 * This was validated experimentally. The effective rsolution is just shy aboce 11bit in this case.
 *
 * Authors:
 * - Florian Thibaud
 * - Florian Gautier 
 *
 * Heavily inspired, or more accurately shamelessly ripped, from the work of Khoih Hoang https://github.com/khoih-prog
 * More precisely SAMD_PWM  https://github.com/khoih-prog/SAMD_PWM/ . We do not use the library as we do not wnat to patch Arduino core.
 */
#include "wiring_private.h"

#define INVALID_SAMD_PIN 255

#define MAX_16BIT 65535UL

#define MAX_COUNT_16BIT 65536UL

static bool tcEnabled[TCC_INST_NUM + TC_INST_NUM] = { false };

class SAMD21_PWM {
public:

  // dutycycle = 0.0f - 100.0f
  SAMD21_PWM(const uint8_t& pin, const float& frequency, const uint16_t& dutycycle) {
    _pinDesc = g_APinDescription[pin];
    _pinAttr = _pinDesc.ulPinAttribute;

    _tcNum = GetTCNumber(_pinDesc.ulPWMChannel);
    _tcChannel = GetTCChannelNumber(_pinDesc.ulPWMChannel);


    if (_pinAttr & PIN_ATTR_PWM) {
      _pin = pin;
      _frequency = frequency;

      _dutycycle = dutycycle;

      // Calc prescaler and _compareValue
      // Check which timer to use
      if (_tcNum >= TCC_INST_NUM) {
        calcTCPrescaler(frequency);
      } else {
        calcTCCPrescaler(frequency);
      }

      pinMode(pin, OUTPUT);

      return;
    }
  }

  ~SAMD21_PWM() {};

private:

  void calcTCCPrescaler(const float& frequency) {
    uint32_t period = 1000000 / frequency;

    if (period > 300000) {
      // Set prescaler to 1024
      _prescalerConfigBits = TC_CTRLA_PRESCALER_DIV1024;
      _prescaler = 1024;
    } else if (80000 < period && period <= 300000) {
      // Set prescaler to 256
      _prescalerConfigBits = TC_CTRLA_PRESCALER_DIV256;
      _prescaler = 256;
    } else if (20000 < period && period <= 80000) {
      // Set prescaler to 64
      _prescalerConfigBits = TC_CTRLA_PRESCALER_DIV64;
      _prescaler = 64;
    } else if (10000 < period && period <= 20000) {
      // Set prescaler to 16
      _prescalerConfigBits = TC_CTRLA_PRESCALER_DIV16;
      _prescaler = 16;
    } else if (5000 < period && period <= 10000) {
      // Set prescaler to 8
      _prescalerConfigBits = TC_CTRLA_PRESCALER_DIV8;
      _prescaler = 8;
    } else if (2500 < period && period <= 5000) {
      // Set prescaler to 4
      _prescalerConfigBits = TC_CTRLA_PRESCALER_DIV4;
      _prescaler = 4;
    } else if (1000 < period && period <= 2500) {
      // Set prescaler to 2
      _prescalerConfigBits = TC_CTRLA_PRESCALER_DIV2;
      _prescaler = 2;
    } else if (period <= 1000) {
      // Set prescaler to 1
      _prescalerConfigBits = TC_CTRLA_PRESCALER_DIV1;
      _prescaler = 1;
    }

    _compareValue = (uint32_t)(F_CPU / (_prescaler / (period / 1000000.0))) - 1;
  }

  // _compareValue max 8-bit = 255
  void calcTCPrescaler(const float& frequency) {
    uint32_t period = 1000000 / frequency;

    uint32_t newPeriod = period / 256;

    if (newPeriod > 300000) {
      // Set prescaler to 1024
      _prescalerConfigBits = TC_CTRLA_PRESCALER_DIV1024;
      _prescaler = 1024;
    } else if (80000 < newPeriod && newPeriod <= 300000) {
      // Set prescaler to 256
      _prescalerConfigBits = TC_CTRLA_PRESCALER_DIV256;
      _prescaler = 256;
    } else if (20000 < newPeriod && newPeriod <= 80000) {
      // Set prescaler to 64
      _prescalerConfigBits = TC_CTRLA_PRESCALER_DIV64;
      _prescaler = 64;
    } else if (10000 < newPeriod && newPeriod <= 20000) {
      // Set prescaler to 16
      _prescalerConfigBits = TC_CTRLA_PRESCALER_DIV16;
      _prescaler = 16;
    } else if (5000 < newPeriod && newPeriod <= 10000) {
      // Set prescaler to 8
      _prescalerConfigBits = TC_CTRLA_PRESCALER_DIV8;
      _prescaler = 8;
    } else if (2500 < newPeriod && newPeriod <= 5000) {
      // Set prescaler to 4
      _prescalerConfigBits = TC_CTRLA_PRESCALER_DIV4;
      _prescaler = 4;
    } else if (1000 < newPeriod && newPeriod <= 2500) {
      // Set prescaler to 2
      _prescalerConfigBits = TC_CTRLA_PRESCALER_DIV2;
      _prescaler = 2;
    } else if (newPeriod <= 1000) {
      // Set prescaler to 1
      _prescalerConfigBits = TC_CTRLA_PRESCALER_DIV1;
      _prescaler = 1;
    }

    _compareValue = (uint32_t)(F_CPU / (_prescaler / (period / 1000000.0))) - 1;
  }
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

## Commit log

2025-03-26 Commenting pin layout conflict
2025-03-26 Driver .Net project init
2025-03-28 [kicad] - initialisation projet + première proposition de schéma
    [ascom-flat-panel.kicad_pcb, ascom-flat-panel.kicad_sch]
2025-03-28 ajout des bibliothèque de symboles et empreintes Seeeduino XIAO + mise à jour du schéma avec ces éléments + draft de pcb
    [ascom-flat-panel.kicad_pcb, ascom-flat-panel.kicad_sch]
2025-03-28 Calls to device implementation
2025-03-28 First driver full implem
2025-03-28 Check also that ther is a non null serial driver in the the IsConnected function
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2025-03-29 Clearer error message for device validation
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2025-03-29 Driver state was set before the hardware did actually try to connect (#2)
2025-03-30 Première mise en forme et routage du circuit - ajout modèle3D seeeduino
    [ascom-flat-panel.kicad_pcb, ascom-flat-panel.kicad_sch]
2025-03-31 ajout perçage pour fixation + réajustement position logo club
    [ascom-flat-panel.kicad_pcb]
2025-03-31 Fix ascom driver concurrency (#3)
    * Mocking firmware for nominal scenario testing
    * Should be ok for firmware testing
    * Housekeeping
    * Proper validation
    * House keeping
2025-03-31 ajout des tolérances pcbway + quelques optimisations de routage (supression de vias)
    [ascom-flat-panel.kicad_pcb]
2025-03-31 optimisation (rotation de diode)
    [ascom-flat-panel.kicad_pcb]
2025-03-31 correction suite à détection d'erreur...
    [ascom-flat-panel.kicad_pcb]
2025-03-31 Remplissage cartouche du schéma
    [ascom-flat-panel.kicad_sch]
2025-03-31 Corrections de routage pour améliorer les connexions à la masse
    [ascom-flat-panel.kicad_pcb]
2025-04-01 Ft init indi driver (#5)
    * Indi driver init and directories layout adjustements
    * Refactoring documentation
2025-04-02 Mise à jour des références des diodes et MOSFET suivant composants achetés. TODO : vérifier pas et diamètre de C1 - ajuster empreinte le cas échéant
    [ascom-flat-panel.kicad_pcb, ascom-flat-panel.kicad_sch]
2025-04-02 ajout logo club en gros sur couche inférieure
    [ascom-flat-panel.kicad_pcb]
2025-04-02 Ajout des VRAIES (a priori) design rules pcbway et petites modifications de routage pour s'y conformer
    [ascom-flat-panel.kicad_pcb]
2025-04-02 réajustements de routage...
    [ascom-flat-panel.kicad_pcb]
2025-04-02 Fix small mistakes and typos (#6)
    * Fix: Separators validation was logically incorrect
    * Fix: correct error message when panel not calibrated
    * Fix: Typos in firmware ino file top comment
    * Fix : Typos a bit everywhere
    [arduino_firmware.ino]
2025-04-03 Fix minor changes (#7)
    * Consistency with command verbosity
    * Typos typos typos everywhere
    [arduino_firmware.ino]
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2025-04-08 [kicad] - changements de variables d'environnement pour garantir la portabilité du projet. La bibliothèque d'empreintes et le modèle 3D sont en outre déplacés dans le répertoire du projet. A TESTER !
    [ascom-flat-panel.kicad_pcb, ascom-flat-panel.kicad_sch]
2025-04-08 [kicad] - schéma : alimentation des LEDs passée de 3V3 à 5V suite aux tests
    [ascom-flat-panel.kicad_sch]
2025-04-08 [kicad] - modification du pcb pour l'alimentation des LEDs en cohérence avec le schéma + réparation portabilité modèle 3D...
    [ascom-flat-panel.kicad_pcb]
2025-04-08 [kicad] - mise à jour valeur résistance 5k -> 4k7 suivant tests + ajustement de routage
    [ascom-flat-panel.kicad_pcb, ascom-flat-panel.kicad_sch]
2025-04-08 [kicad] - renommage connecteur J3 -> J2
    [ascom-flat-panel.kicad_pcb, ascom-flat-panel.kicad_sch]
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2025-04-08 Ft init 3d models (#10)
    * Init models with 100mm diam led panel
    * Adding models entry in readme
    [fffpv1-100mm_led_pan_diam.FCStd]
2025-04-21 Ft kicad update (#11)
    * [kicad] - Modification empreinte du Condensateur par cohérence avec les composants reçus (diam 6.3 au lieu de 5)
    * [kicad] - suppression du plan de masse de la couche supérieure de cuivre, a priori inutilisé
    * [kicad] - Modif suite aux tests servo : valeur R2 + routage connecteur
    * [kicad] - optimisation placement des connecteurs
    * [kicad] - suppression des vias, ajustement des trous (M2) et arrondi des angles
    * [ASCOM] Revert fake cover status quick fix
    * [FIRMWARE] Tweaking servo pins names and values to match schematics
    ---------
    [ascom-flat-panel.kicad_pcb, ascom-flat-panel.kicad_sch]
2025-04-22 [firmware] - Using calibration data to send correct command to servo
    [arduino_firmware.ino]
2025-04-22 [firmware] - Properly reverting current position checks
    [arduino_firmware.ino]
2025-04-23 Fix calibration consistency (#13)
    * [firmware] - Delay before calibration and finer steps
    * [documentation] - Correct calibration command name
    [arduino_firmware.ino]
2025-04-27 [kicad] - suppression des 2 couches internes de Cu inutiles suite à reviex pcbway. Mise à jour du pcb et des fichiers gerber (#14)
    * [kicad] - génération des fichiers pour la commande !!
    * [kicad] - suppression des 2 couches internes de Cu inutiles suite à reviex pcbway. Mise à jour du pcb et des fichiers gerber
    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
    [ascom-flat-panel.kicad_pcb]
2025-05-14 [firmware] - Blinking leds should be non blocking (#15)
    * [firmware] - Blinking led mechanism relies on timers
    * [firmware] - Folder layout adjustements and typos correction
    [fffpv1_firmware.ino]
2025-05-14 [firmaware] - Status LED is ON during calibration (#16)
2025-06-03 [3D Model] Intégration et finalisation modèle 3D proto (#17)
    * [3D] - intialisation boite pcb. TODO :
    - passe cables
    - trous pour fixation à la pince
    - support aimants
    - ajustement position USB-C (en particulier prendre en compte épaisseurs connecteurs seeduino)
    * [3D] adapting clamp head to servo box size
    * [3D] - First cover implem
    * [3D] - mise en cohérence taille visserie boite pcb avec jlecomte
    * [3D] - ajustement position trou usb C suite aux mesures sur carte seeeduino
    * [3D] - circuit box : encapsulement dans un objet Part
    * [3D] - circuit box : correction de la parametrisation de la position du seeeduino
    * [3D] - circuit box : ajout d'un bracket de fixation repris de jle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
    [Logo.FCStd, ServoBoxInserts.FCStd, fffpv1-100mm_led_pan_diam.FCStd]
2025-06-03 [project] layout coherence (#18)
    [ascom-flat-panel.kicad_pcb, ascom-flat-panel.kicad_sch]
2025-06-20 [Project] Corrections following beta prototype testing (#20)
    * [3D] - correction intégration logo (plus de dépassement du plan du boîtier)
    * [3D] - logo - correction de caractères n'ayant pas bien supporté la mise à l'échelle
    * [Installer] Add ASCOM driver installer script
    * [driver] Enabling driver installer welcome page
    * [3D] - inserts dans servo box implémentés dans modèle principal
    * [Firmware-Driver] 16bits hardware base pwm
    * [Firmware] Minor tweaks
    * [Driver] Remove unused imports
    * [3D] - Circuit Box : inserts + aimants en surface
    * [3D] - aimants du couvercle du panneau en surface
    * [3D] - chanfreins sur les cavités pour aimants
    * [3D] - réduction du diamètr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
    [Logo.FCStd, ServoBoxInserts.FCStd, fffpv1-100mm_led_pan_diam.FCStd]
2025-06-21 [Circuit] Add a circuit option for a +3V3 output for LEDS (#21)
    * [circuit] LEDS on 3V Ki-Cad project init
    * [circuit] Schematics update for 3V3 leds
    * [circuit] Add decoupling capacitor betwenn +3V3 and GND
    * [circuit] PCB modified accordingly to schematics
    [Seeeduino XIAO SAMD21 v4.step, ascom-flat-panel.kicad_pcb, ascom-flat-panel.kicad_sch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]
2025-06-23 [electronics] Various fixes for the 3v output led circuit (#22)
    * micro ajustement cosmétique
    * mise à jour des fichiers de fab
    * suppression des fichiers de fab 5V et 3V -> à mettre en release
    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
    [ascom-flat-panel.kicad_pcb]
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2025-06-29 [documenation] Driver unit testing has its own section
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2025-07-05 [firmware] Quick fix for small initial jerk on plug
    [fffpv1_firmware.ino]
2025-07-05 [firware] wait for connection before pwm and servo inti
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2025-07-08 [firmware] Correcting comment concerning the disconnect event handler.
    [fffpv1_firmware.ino]
2025-07-29 [3D] - réduction (-0,5 mm) de l'épaisseur du spacer/diffuseur
    [fffpv1-100mm_led_pan_diam.FCStd]
2025-07-29 [3D] - perçage de 6 trous de fixations du couvercle au lieu de 3 + approfondissement des trous d'inserts correspondants
    [fffpv1-100mm_led_pan_diam.FCStd]
2025-07-30 [3D] - agrandissement trous vis/écrou M4
    [fffpv1-100mm_led_pan_diam.FCStd]
2025-07-30 [3D] - élargissement trous inserts M3 (+0.2 mm)
    [fffpv1-100mm_led_pan_diam.FCStd]
2025-07-30 [3D] - paramétrisation et élargissement (+0,2mm) des emplacements pour les aimants
    [fffpv1-100mm_led_pan_diam.FCStd]
2025-07-31 [3D] - passe d'assainissement de la géométrie
    [fffpv1-100mm_led_pan_diam.FCStd]
2025-12-29 [feat.] V2 of firmware and ASCOM driver (#24)
    * Port of the firrmware to PlatformIO
    * Port of the driver to ASCOM 7
    * Installer for ASCOM 7 driver
    * Documenting what's coming with v2
    * Removing v1 drivers and firmware
2025-12-30 Fix: Various firmware minor bugs and typos (#25)
    * Match plateformio monitor speed with FFFP speed
    * Make sure headers are included only once
    * Cons vs constexpr in allowed_cmds
    * Various typos in command names and comments
    [main.cpp]
2026-05-21 [feat. v2] Full implementation of EL panel as light source (#28)
    * [Electronics] - PCB and schmetaics with EL driver
    * [Drivers] ASCOM 7 and Indi drivers
    * [Firmware] New commands available for dynamic versions and max brightness
    * [3D] Fully scalable 3D model
    * [3D] Added dew heaters
    * And more...
    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
    [EpreuveSpirale.FCStd, Seeeduino XIAO SAMD21 v4.step, ascom-flat-panel.kicad_pcb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]
2026-06-27 v2 Ready for beta 1 release (#29)
    * [Model] ajout d'un jeu (0.2 mm) entre le bushing et le bras (modèle 160 uniquement pour l'instant)
    * [Model] augmentation du diamètre externe des trous de fixation du bras gauche au coupleur servo
    * [Firmware] Fix: Servo spins in oposite directions depending on wheater it's a LED panel or EL panel build
    * [Specifications] Fix: Missing v2 commands specifications and typos
    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
    [fffpv2-160mm_el_panel_diam.FCStd]
